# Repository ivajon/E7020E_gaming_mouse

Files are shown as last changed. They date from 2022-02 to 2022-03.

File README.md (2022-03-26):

# Awesome gaming mouse
The awesome gaming mouse project, the one mouse to rule them all. The schematics
are available [here](schematics_and_pcb). The firmware for the mouse is written in rust using [rtic](https://rtic.rs/) and is found [here](code/e7020e_rtic) the rtic app is in the example [rtic_simple_mouse](code/e7020e_rtic/examples/rtic_simple_mouse.rs). The program used to configure the mouse is found [here](code/hosted/rust_version).

## How to flash the mouse
To flash the mouse read [this](e7020e-project/code/e7020_rtic/README.md) to get the build dependecies. When the dependencis are in place it can be built, flashed and run with `cargo run --example rtic_simple_mouse --release`. Note! it can't be built in debug mode since this will create to big of a binary and will not fit on the flash of a stm32f401re.

## Members

- Erik Serrander
- eriser-8@student.ltu.se
  
- Ivar Jönsson
- ivajns-9@student.ltu.se

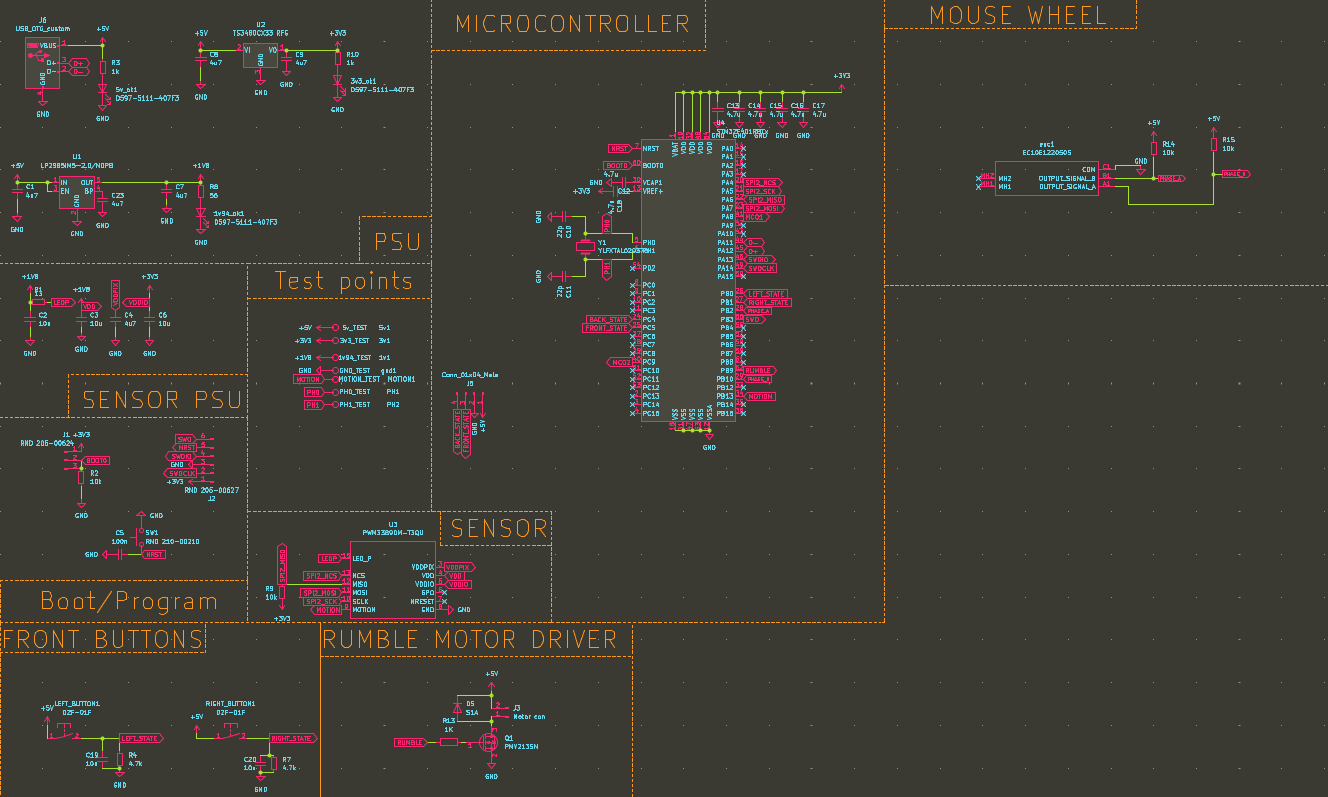
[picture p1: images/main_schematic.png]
main schematic


## High level specification

### Basic
- [x] Left and right click
- [x] relative position

### Higher
- [x] scroll wheel
- [x] macro system
- [x] Side buttons

### Stretch
- [x] Computer communication
- [ ] LEDs, i.e. debug/ui
- [ ] Rumble motor
- [ ] Perfect spray

### Implementation
- Unit testing
- Cuntinuous integration

# Specifications
## Mouse buttons
The buttons used are [D2F-01F](https://www.elfa.se/sv/mikrobrytare-d2f-100ma-1co-74n-kolv-omron-electronic-components-d2f-01f/p/11082662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) since these are well regarded by users.
We have decided to have 4 main buttons on the mouse, 2 on the front and 2 on the side.
## Side buttons 
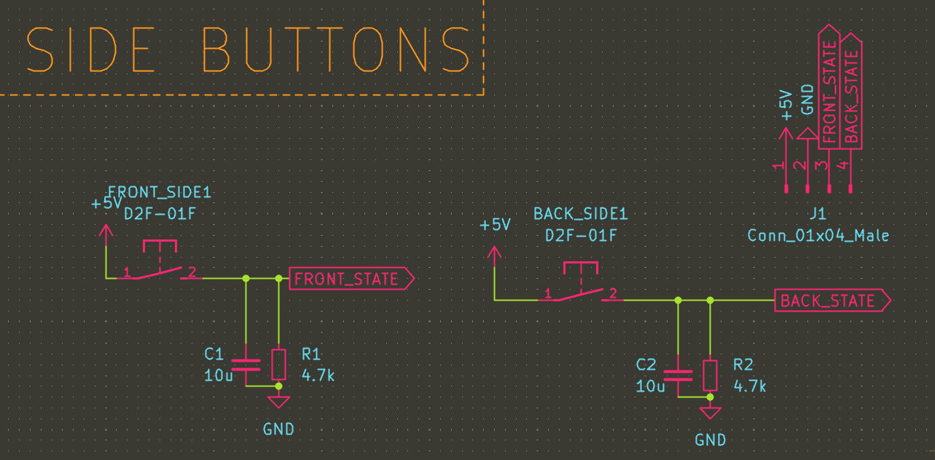
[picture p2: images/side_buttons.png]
side_buttons

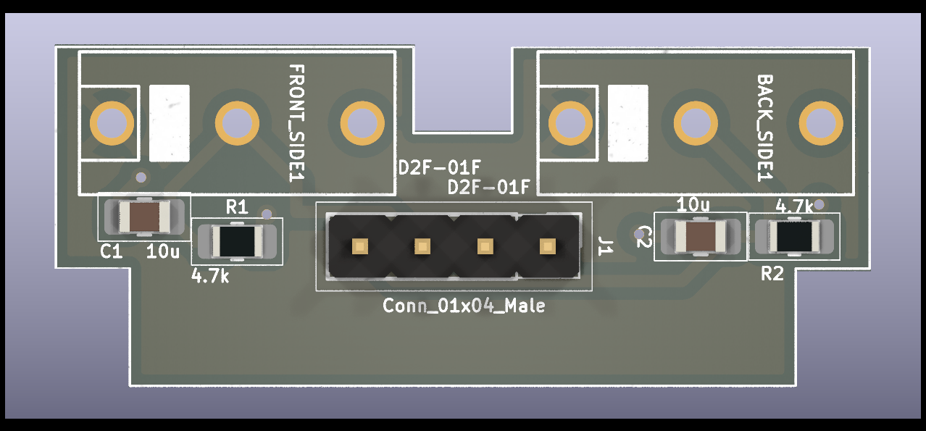
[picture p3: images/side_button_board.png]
side_pcb

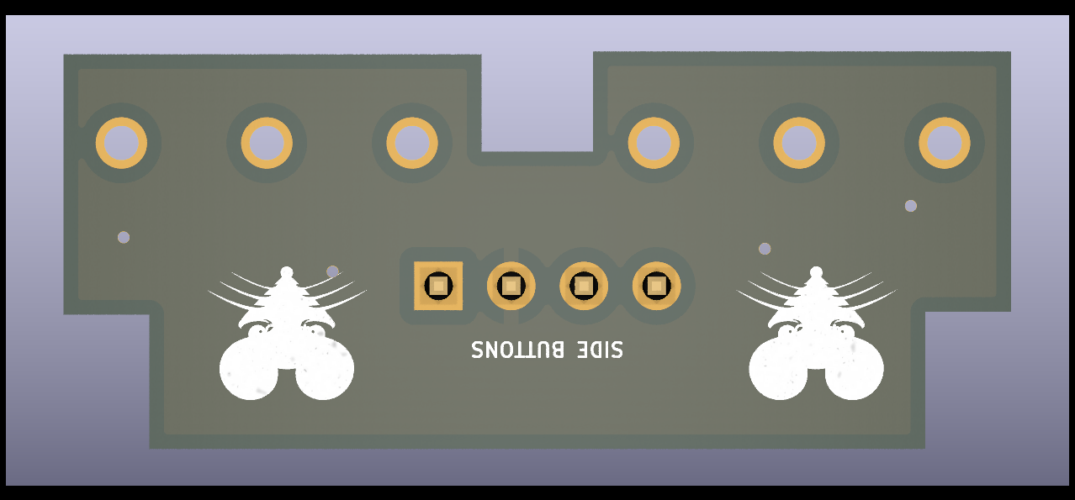
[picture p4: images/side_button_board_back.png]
side_pcb


To reduce the bouncing of the buttons a 10u capacitor is places to ground from the signal trace. This will allow the signal to be pulled low for high frequencies. 

To drive the buttons a 5v voltage is used with a series resistor of 4.7 k to limit the current to close to 1mA. The mosfet used to limit the output acts as a decoupler thus not draining anny current ( in theory ).

## Front buttons
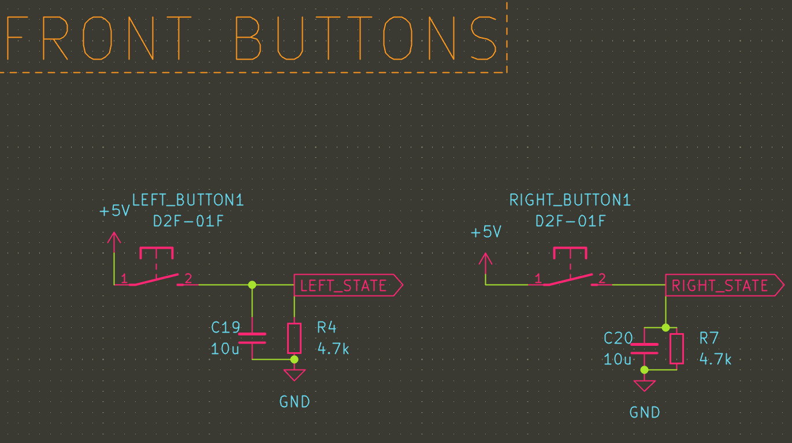
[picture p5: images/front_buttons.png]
front_buttons

## Mouse wheel

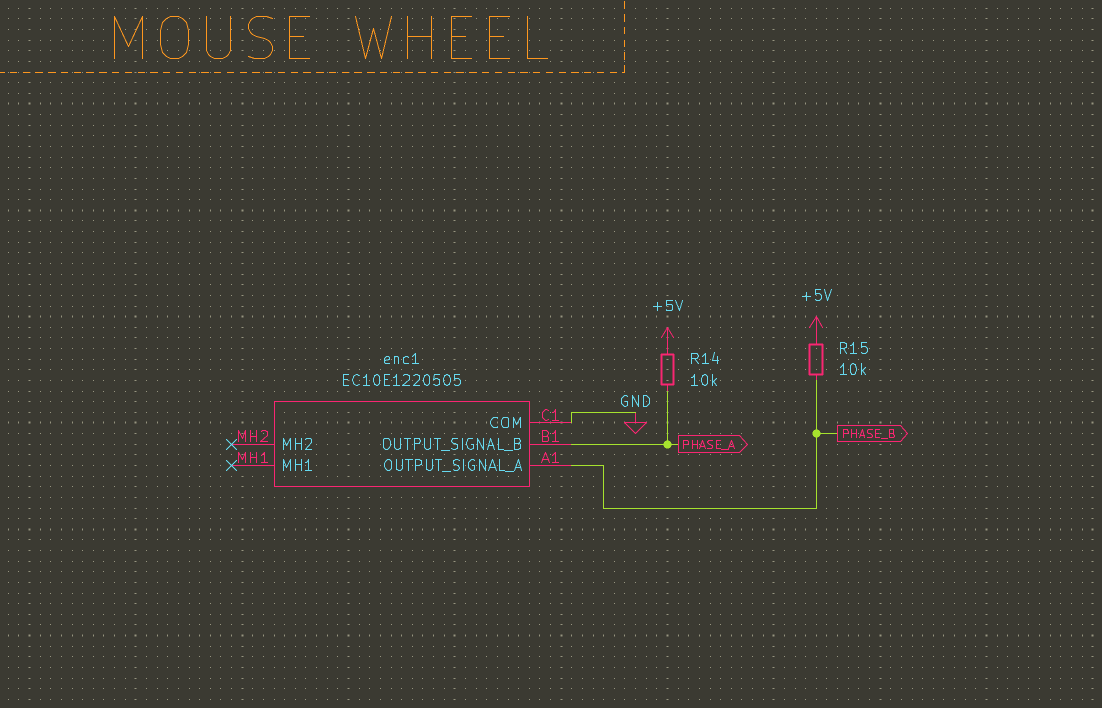
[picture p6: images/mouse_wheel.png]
mouse_wheel


The [mouse wheel](https://se.rs-online.com/web/p/mechanical-rotary-encoders/7295545) is also debounced using the same capacitor values as the mouse button. This should not be as needed but better safe than sorry.

The mouse wheel also uses the same nfet to step down the voltage.

## Rumble motor
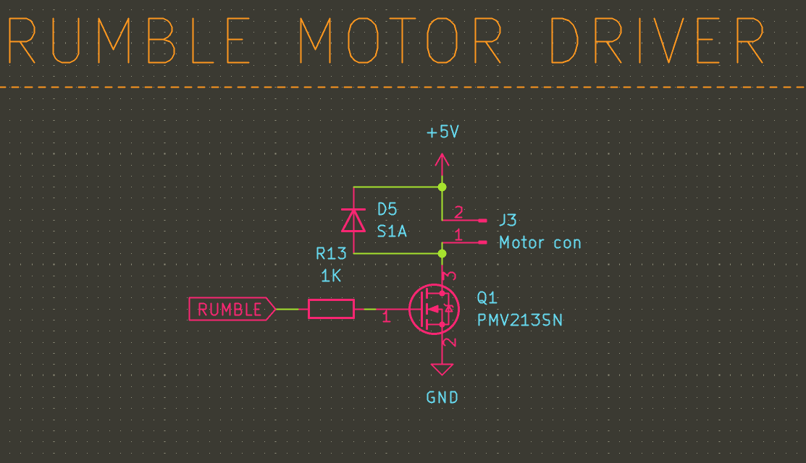
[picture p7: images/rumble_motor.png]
Rumble motor image


## Main board
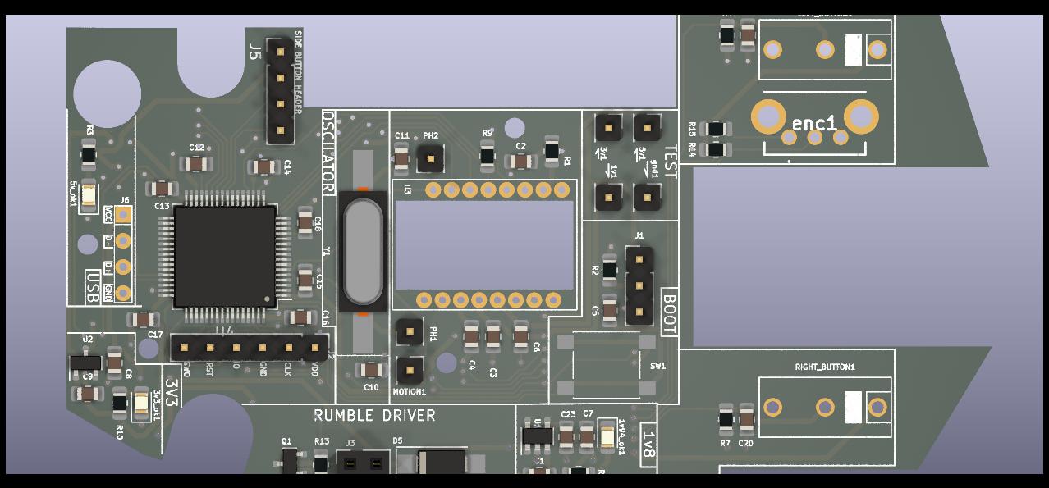
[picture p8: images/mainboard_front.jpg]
main board

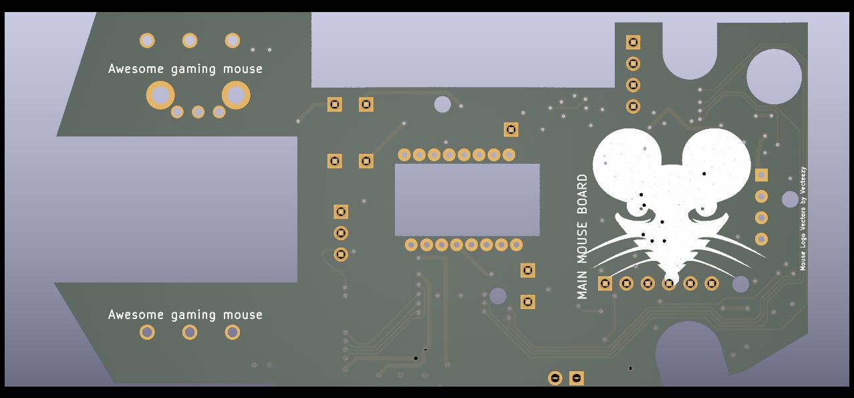
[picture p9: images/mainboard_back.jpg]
main board back


## Case 
We will base our case on this moddel of the [g305](https://www.thingiverse.com/thing:3969266)
with this [base](https://www.thingiverse.com/thing:3564894).

The stl files can be found in our [model folder](model/).

## Grading

- Erik Serrander
  - Expected contributions towards grade 4
    - side buttons
    - diodes
  - Expected contributions towards grade 5
    - Computer communication
    - Rumble motor
  
- Ivar Jönsson
  - Expected contributions towards grade 4
    - PCB layout
      - Itterative design using a 3d printer to validate pcb fitting and footprint layout
      - Ease of assembly
    - Case customization 
      - Mountingholes and posibility to use a usb cable
    - Mouse wheel
      - Selecting a rotary encoder
    - diodes
      - status LEDs to validate voltage sections
  - Expected contributions towards grade 5
    - Computer communication
    - DPI configuration
    - Perfect spray
      - This might not be applicable. 

## contributions

- Erik Serrander
  - Hardware design (werry minor)
  - Macro system
  - Macro system config mouse side
  - Mouse state software (major)

- Ivar Jönsson
  - Hardware design (allmost all)
  - Macro system config pc side
  - Mouse state software (minor)
  - Enclosure manufacturing

- Togheter / both
  - Init code
  - Interuppt handlers
  - Harware assembly

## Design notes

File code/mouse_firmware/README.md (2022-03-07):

# RTIC on the STM32F4xx Nucleo board

All tooling have been developed and tested under Linux. Any modern Linux distro should work, we usually recommend Arch linux as it provides a great package manager with rolling releases. If you want to run Arch, but don't want to install everything from scratch, you may opt for [Manjaro](https://manjaro.org/) or [Endeavour](https://endeavouros.com/). You will get the best user experience by a native install, but you may run Linux under a VM like virtualbox, or vmware (the player is free). You should install the guest extensions, to get better graphics performance (and perhaps better USB forwarding). Since you will connect your Nucleo using USB, you must make sure that USB port forwarding works (the Nucleo stlink programmer is a USB2 device running in full speed 12MBit).

This repo will be updated with more information throughout the course so please check the `CHANGELOG.md` and recent commits to see what has changed. (You should `pull` the upstream to keep your repository updated.) If you have suggestions to further improvements, please raise an issue and/or create a merge/pull request.

## Rust

We assume Rust to be installed using [rustup](https://www.rust-lang.org/tools/install).

Additionally you need to install the `thumbv7em-none-eabihf` target.

```shell
> rustup target add thumbv7em-none-eabihf 
```

You also need [cargo-binutils](https://github.com/rust-embedded/cargo-binutils), for inspecting the generated binaries. You install Rust applications through `cargo`

```shell
> cargo install cargo-binutils
```

There are a number of other useful [cargo subcommands](https://github.com/rust-lang/cargo/wiki/Third-party-cargo-subcommands).

- [cargo-bloat](https://crates.io/crates/cargo-bloat), for info on the size of different sections of the generated binary,
- [cargo-tree](https://crates.io/crates/cargo-tree) (that list your dependency tree), etc.

## For RTT tracing

Install the [probe-run](https://crates.io/crates/probe-run) tool.

```shell
> cargo install probe-run
```

Install the [cargo-embed](https://github.com/probe-rs/cargo-embed) tool.

```shell
> cargo install cargo-embed
```

Or for the latest git version, with improved support for blocking writes in case buffer space is depleted.

```shell
> cargo install --git https://github.com/probe-rs/cargo-embed.git
```

## For `itm` tracing in terminal

The SWO output pin of the MCU is used to transmit trace information over a single serial wire. The onboard Nucleo `stlink` programmer has an SWO input pin (by default connected to the target MCU). You can setup `openocd` to forward the serial communication to a file (or pipe). In order to view the trace as text, the serial stream needs to be decoded by some tool (e.g., the `itmdump` utility or the built in decoder in `Cortex Debug`). To install `itmdump`:

```shell
> cargo install itm
```

## For programming and low-level `gdb` based debugging

Use your Linux package manager to install the following tools:

- `stlink`, this package will install programming utilities like `st-flash` (useful if you need to recover a bricked target by erasing the flash), and setup `udev` rules, allowing you to access the USB device without `sudo`. Install may require you to login/logout to have new `udev` rules applied.

- `arm-none-eabi-gdb` (Arch), or `gdb-multiarch` (Ubuntu etc.). This tool allows you to program (flash) and debug your target.

- `openocd`, this tool allows the host to connect to the (stlink) programmer. The scripts used assume the latest `openocd-git` (0.11.0+dev).

  Under Arch: The official package (as of 2022-02-13) relates to a released 0.11.0 version of `openocd`, and will not likely work, you need a `dev` version. You can either install from source [openocd](https://github.com/openocd-org/openocd), or easier using a prepared package build:
  - Clone my repo [openocd-git](https://github.com/perlindgren/openocd-git/). (The official `aur` is outdated, so I made a fix.)

  - Install the package:

    ```shell
    > makepkg -si
    ```

  - Trouble shooting. If it fails to compile you might be missing some dependency provided by the `base-devel` package.
  
    ```shell
    > pacman -S base-devel
    ```

  Other Linux distributions: Either install from source or find a package relating to the git version of `openocd`.

- [stlink](https://www.st.com/en/development-tools/stsw-link007.html), firmware for the `st-link` programmer on your Nucleo board. You can obtain it free from ST web site, or under Arch use the `aur` package [stsw-link007](https://aur.archlinux.org/packages/stsw-link007). To run the firmware update in Arch:
  
  ```shell
  >STLinkUpgrade
  ```

  Once the Java application started you can flash a new firmware.
  Choose `Open in update mode`, leave `Change type` unchecked and click `Upgrade`.

## Editor

You may use any editor of choice. We recommend `vscode`, the `rust-analyzer` and `Cortex Debug` plugins. There are many other great plugins for improved git integration, `.md` linting and preview etc.

In the `.vscode` folder of this project, you find a number of configuration files (`launch.json` for target debugging, `tasks.json` for building, etc.), that facilitates embedded Rust development.

## Useful Resources

- Nucleo 64
  - [UM1724 - stm32 Nucleo-64](https://www.st.com/resource/en/user_manual/dm00105823-stm32-nucleo64-boards-mb1136-stmicroelectronics.pdf).
  - [Nucleo 64 Schematics](https://www.st.com/resource/en/schematic_pack/nucleo_64pins_sch.zip) (The file MB1136.pdf is the schematics in pdf.)
  - [stm32f4xx_hal](https://docs.rs/stm32f4xx-hal/0.8.3/stm32f4xx_hal/) documentation of the HAL API, and [git repository](https://github.com/stm32-rs/stm32f4xx-hal).

- STM32F01/FO11
  - [RM0383 - F411 Reference Manual](https://www.st.com/resource/zh/reference_manual/dm00119316-stm32f411xce-advanced-armbased-32bit-mcus-stmicroelectronics.pdf) 
  - [RM0368 - F401 Reference Manual](https://www.st.com/resource/en/reference_manual/dm00096844-stm32f401xbc-and-stm32f401xde-advanced-armbased-32bit-mcus-stmicroelectronics.pdf)
  - [PM0214 - M4 Programming manual](https://www.google.com/url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)

- PixArt PMW33xx Optical Navigation Chip
  - [PMW3389DM-T3QU](https://www.google.com/url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), optical navigation chip
  - [Jack Enterprise Breakout Board](https://www.tindie.com/products/jkicklighter/pmw3389-motion-sensor/), an example design with software linked.

- General Embedded
  - [Introduction to SPI](https://www.analog.com/en/analog-dialogue/articles/introduction-to-spi-interface.html#), a short introduction to the SPI interface.

---

## Examples

### Terminal trace using RTT

Select the runner in `.cargo/config.toml`:

```shell
runner = "probe-run --chip STM32F411RETx"
```

Run your application from terminal:

```shell
> cargo run --example rtt_rtic_hello
```

Tracing of panics is supported by the `panic_rtt` crate.

---

### VSCODE based debug and trace

Some simple bare metal examples for you to try out before starting to run your own code: (Here we assume the tools mentioned above have been successfully installed into their default locations. If you installed manually, you may need to tweak paths accordingly, ask in the `software` channel on Discord if you run into some trouble.)

Using `vscode` just press F5 to launch and debug the program in the currently active `vscode` window.

- `rtic_hello.rs`, this example uses semihosting to print the output terminal. In `vscode`:
  - `Terminal` pane `gdb-server` shows the `openocd` session (your semihosting trace will be displayed there).
  - `DEBUG CONSOLE` pane shows the `gdb` session. You can use this to interact directly with the target (over openocd).

- `itm_rtic_hello.rs`, this examples uses the ITM trace to print to trace channel 0. The `Terminal` pane `SWO:ITM[port:0] console]` will display the ITM trace.

- `rtic_panic.rs`, this example shows how to trace panic messages (in this case over semihosting).  Open the `Terminal` pane and select `gdb-server` (which is the `openocd` console).
  
---

### Terminal trace using semihosting

Select the runner in `.cargo/config.toml` according to your `gdb` install, e.g.:

```shell
runner = "arm-none-eabi-gdb -q -x openocd.gdb"
```

Start `openocd` in a separate terminal:

```shell
> openocd -f openocd.cfg
```

Run the application: e.g.

```shell
> cargo run rtic_hello
```

The `openocd.gdb` script is used to setup the behavior of the debug session, you may change it to your liking. (The default script puts breakpoints at `DefaultHandler`, `HardFault` and `main`, edit it for your needs.)

```shell
> cargo run rtic_hello
```

---

### Terminal trace using ITM

Setup the runner as for previous example.

To setup a fifo for the ITM stream and start sniffing:

```shell
> mkfifo /tmp/itm.fifo
> itmdump -F -f /tmp/itm.fifo
```

The `-F` instructs `itmdump` to follow the stream.

Start the `openocd` session in a separate terminal.

```shell
> openocd -f openocd.cfg
```

Start the `gdb` session in a separate terminal.

```shell
> cargo run ....
```

This, in this scenario you will have three terminals running:

- `itmdump`, to decoded and echo the ITM stream,
  
- `openocd`, to communicate to the programmer and provide a gdb-server,
  
- `arm-none-eabi-gdb`, to debug our application.

ITM traces should now appear in the `itmdump` terminal and semihosting traces in the `openocd` terminal.

---

### Gdb the GNU debugger

Gdb offers a lot of functionality, you may even write scripts in python to automate debugging. For a summary of commands see e.g., [gdb-refcard](http://fac-staff.seattleu.edu/elarson/web/Linux/gdb-refcard.pdf).

Many of the commands can be executed from the `DEBUG CONSOLE` in `vscode`.

---

### Concluding remarks on debug and trace

Chose the approach and tools dependent on your application needs. If plain tracing  is sufficient chose `probe run`. If you need to interactively debug your application, use `gdb` based trace and debug instead. ITM is preferred over semihosting for real-time applications.

You may also look at [defmt](https://crates.io/crates/defmt), it supports deferred formatting to reduce the run-time overhead (on the target).

---

### Exercises

Bare metal programming:

- `examples/rtic_bare1.rs`, in this exercise you learn about debugging, inspecting the generated assembly code, inline assembly, and about checked vs. unchecked (wrapping) arithmetics. Provides essential skills and understanding of low level (bare metal) programming.
- `examples/rtic_bare2.rs`, in this exercise you learn how to measure execution time using raw timer access.
- `examples/rtic_bare3.rs`, here you learn more about RTIC timing semantics and timing abstractions.
- `examples/rtic_bare4.rs`, in this exercise you will encounter a simple bare metal peripheral access API. The API is very unsafe and easy to misuse.
- `examples/rtic_bare5.rs`, here you will write your own C-like peripheral access API. This API is much safer as you get control over bit-fields in a well defined way, thus less error prone.

---

## Troubleshooting

---

### Fail to connect or program (flash) your target

- Make sure you have the latest version of the [stlink](https://www.st.com/en/development-tools/stsw-link007.html) firmware (V2J39M27 or later).

- Check that your stlink Nucleo programmer is found by the host.

  ```shell
  > lsusb
  ...
  Bus 003 Device 013: ID 0483:374b STMicroelectronics ST-LINK/V2.1
  ...
  ```

  If not check your USB cable. Notice, you need a USB data cable (not a USB charging cable).
  If the problem is still there, there might be a USB issue with the host (or VM if you run Linux under a VM that is).

- If you get a connection error similar to the below:

  ```shell
  > openocd -f openocd.cfg
  Open On-Chip Debugger 0.11.0+dev-00562-g5ab74bde0 (2022-02-09-11:34)
  Licensed under GNU GPL v2
  For bug reports, read
          http://openocd.org/doc/doxygen/bugs.html
  Info : auto-selecting first available session transport "hla_swd". To override use 'transport select <transport>'.
  Info : The selected transport took over low-level target control. The results might differ compared to plain JTAG/SWD
  Info : Listening on port 6666 for tcl connections
  Info : Listening on port 4444 for telnet connections
  Info : clock speed 2000 kHz
  Info : STLINK V2J39M27 (API v2) VID:PID 0483:374B
  Info : Target voltage: 3.234098
  Info : stm32f4x.cpu: Cortex-M4 r0p1 processor detected
  Info : stm32f4x.cpu: target has 6 breakpoints, 4 watchpoints
  Info : starting gdb server for stm32f4x.cpu on 3333
  Info : Listening on port 3333 for gdb connection
  Error: jtag status contains invalid mode value - communication failure
  Polling target stm32f4x.cpu failed, trying to reexamine
  Examination failed, GDB will be halted. Polling again in 100ms
  Info : Previous state query failed, trying to reconnect
  Error: jtag status contains invalid mode value - communication failure
  Polling target stm32f4x.cpu failed, trying to reexamine 
  ```

  - First thing to try is holding the reset button while connecting.

  - If this does not work you can try to erase the flash memory (the program running on the STM32F401/F11).

    ``` shell
    > st-flash erase
    st-flash 1.7.0
    2021-06-23T14:07:35 INFO common.c: F4xx (Dynamic Efficency): 96 KiB SRAM, 512 KiB flash in at least 16 KiB pages.
    Mass erasing.......
    ```

  - If this still does not work you can connect `Boot0` to `VDD` (found on CN7 pins 7, and 5 respectively). Unplug/replug the Nucleo and try to erase the flash as above.
  
  - If this still does not work, the Nucleo might actually been damaged, or that the problem is the usb-cable or host   machine related.

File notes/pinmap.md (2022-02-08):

|pin name | pin number | function | interrupt reg|
| --- | --- | --- | --- |
| PB0 | 26 |LEFT_STATE| EXTI line 0 |
| PB1 | 27 |RIGHT_STATE|EXTI line 1 |
| PB2 | 28 | PHASE A | EXT1 line 2 |
| PB3 | 55 |

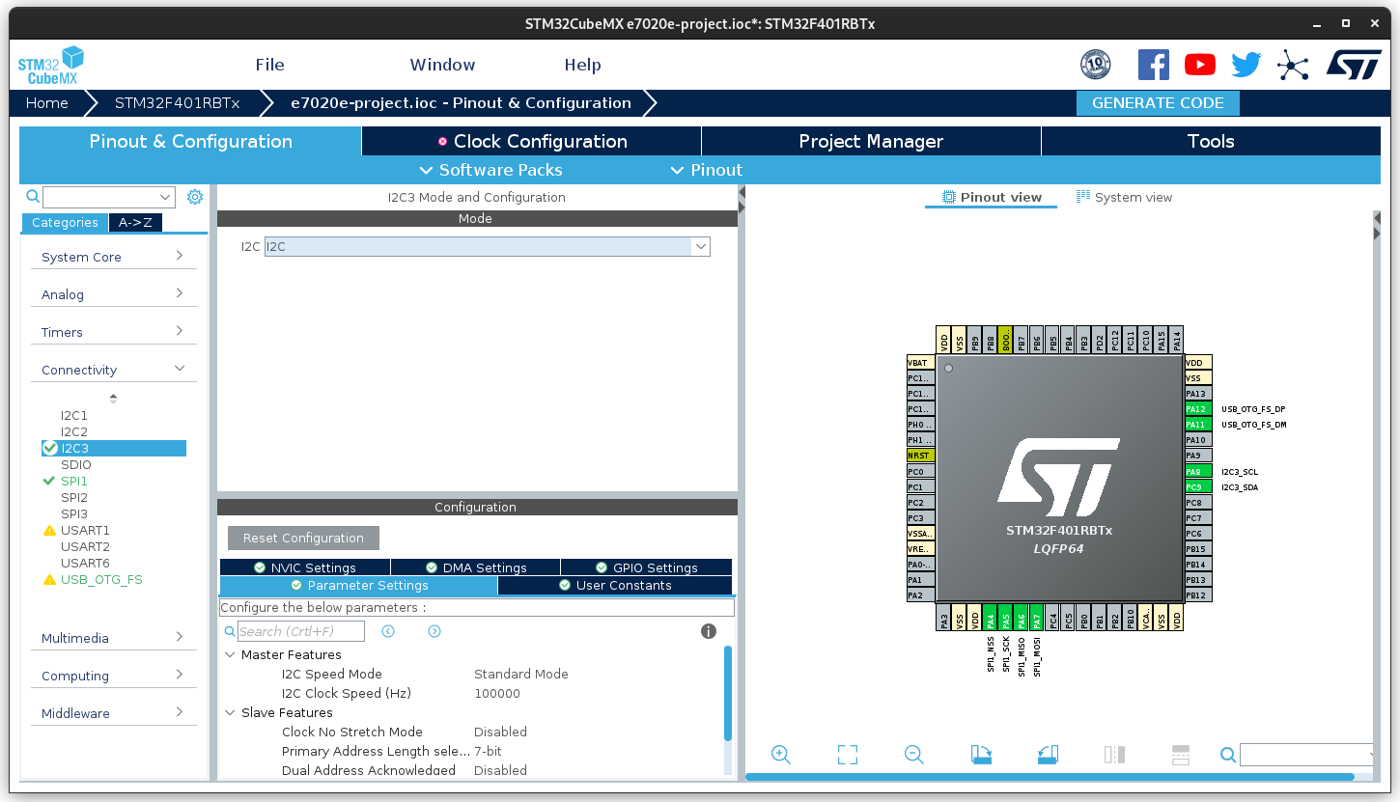
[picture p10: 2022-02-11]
images/Screenshot from 2022-02-11 10-17-43.png

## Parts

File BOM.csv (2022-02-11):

Source: | /home/ivarj/git/project/e7020e-project/schematics_and_pcb/schematics_and_pcb.kicad_sch
Date: | fre 11 feb 2022 14:17:39
Tool: | Eeschema (6.0.1)
Generator: | /usr/share/kicad/plugins/bom_csv_grouped_by_value.py
Component Count: | 82
Individual Components:
Item | Qty | Reference(s) | Value | LibPart | Footprint | Datasheet | Description | Height | Manufacturer_Name | Manufacturer_Part_Number | Mouser Part Number | Mouser Price/Stock | part #
 |  | 1v1 | 1v94_TEST | Connector:TestPoint | Connector_PinHeader_2.54mm:PinHeader_1x01_P2.54mm_Vertical | ~
 |  | 1v94_ok1 | D597-5111-407F3 | Device:LED | LED_SMD:LED_0805_2012Metric_Pad1.15x1.40mm_HandSolder | ~ |  |  |  |  |  |  | D597-5111-407F3
 |  | 3v1 | 3v3_TEST | Connector:TestPoint | Connector_PinHeader_2.54mm:PinHeader_1x01_P2.54mm_Vertical | ~
 |  | 3v3_ok1 | D597-5111-407F3 | Device:LED | LED_SMD:LED_0805_2012Metric_Pad1.15x1.40mm_HandSolder | ~ |  |  |  |  |  |  | D597-5111-407F3
 |  | 5v1 | 5v_TEST | Connector:TestPoint | Connector_PinHeader_2.54mm:PinHeader_1x01_P2.54mm_Vertical | ~
 |  | 5v_ok1 | D597-5111-407F3 | Device:LED | LED_SMD:LED_0805_2012Metric_Pad1.15x1.40mm_HandSolder | ~ |  |  |  |  |  |  | D597-5111-407F3
 |  | BACK_SIDE1 | D2F-01F | mouse:D2F-01F | mouse:D2F-01F
 |  | C1 | 4u7 | Device:C_Small | Capacitor_SMD:C_0805_2012Metric_Pad1.18x1.45mm_HandSolder | ~
 |  | C2 | 10u | Device:C_Small | Capacitor_SMD:C_0805_2012Metric_Pad1.18x1.45mm_HandSolder | ~
 |  | C3 | 10u | Device:C_Small | Capacitor_SMD:C_0805_2012Metric_Pad1.18x1.45mm_HandSolder | ~
 |  | C4 | 4u7 | Device:C_Small | Capacitor_SMD:C_0805_2012Metric_Pad1.18x1.45mm_HandSolder | ~
 |  | C5 | 100n | Device:C_Small | Capacitor_SMD:C_0805_2012Metric_Pad1.18x1.45mm_HandSolder | ~
 |  | C6 | 10u | Device:C_Small | Capacitor_SMD:C_0805_2012Metric_Pad1.18x1.45mm_HandSolder | ~
 |  | C7 | 4u7 | Device:C_Small | Capacitor_SMD:C_0805_2012Metric_Pad1.18x1.45mm_HandSolder | ~
 |  | C8 | 4u7 | Device:C_Small | Capacitor_SMD:C_0805_2012Metric_Pad1.18x1.45mm_HandSolder | ~
 |  | C9 | 4u7 | Device:C_Small | Capacitor_SMD:C_0805_2012Metric_Pad1.18x1.45mm_HandSolder | ~
 |  | C10 | 18p | Device:C_Small | Capacitor_SMD:C_0805_2012Metric_Pad1.18x1.45mm_HandSolder | ~
 |  | C11 | 18p | Device:C_Small | Capacitor_SMD:C_0805_2012Metric_Pad1.18x1.45mm_HandSolder | ~
 |  | C12 | 4.7u | Device:C_Small | Capacitor_SMD:C_0805_2012Metric_Pad1.18x1.45mm_HandSolder | ~
 |  | C13 | 4.7u | Device:C_Small | Capacitor_SMD:C_0805_2012Metric_Pad1.18x1.45mm_HandSolder | ~
 |  | C14 | 4.7u | Device:C_Small | Capacitor_SMD:C_0805_2012Metric_Pad1.18x1.45mm_HandSolder | ~
 |  | C15 | 4.7u | Device:C_Small | Capacitor_SMD:C_0805_2012Metric_Pad1.18x1.45mm_HandSolder | ~
 |  | C16 | 4.7u | Device:C_Small | Capacitor_SMD:C_0805_2012Metric_Pad1.18x1.45mm_HandSolder | ~
 |  | C17 | 4.7u | Device:C_Small | Capacitor_SMD:C_0805_2012Metric_Pad1.18x1.45mm_HandSolder | ~
 |  | C18 | 4.7u | Device:C_Small | Capacitor_SMD:C_0805_2012Metric_Pad1.18x1.45mm_HandSolder | ~
 |  | C19 | 10u | Device:C_Small | Capacitor_SMD:C_0805_2012Metric_Pad1.18x1.45mm_HandSolder | ~
 |  | C20 | 10u | Device:C_Small | Capacitor_SMD:C_0805_2012Metric_Pad1.18x1.45mm_HandSolder | ~
 |  | C21 | 10u | Device:C_Small | Capacitor_SMD:C_0805_2012Metric_Pad1.18x1.45mm_HandSolder | ~
 |  | C22 | 10u | Device:C_Small | Capacitor_SMD:C_0805_2012Metric_Pad1.18x1.45mm_HandSolder | ~
 |  | C23 | 4u7 | Device:C_Small | Capacitor_SMD:C_0805_2012Metric_Pad1.18x1.45mm_HandSolder | ~
 |  | C24 | 10u | Device:C_Small | Capacitor_SMD:C_0805_2012Metric_Pad1.18x1.45mm_HandSolder | ~
 |  | D5 | SS16HE | Diode:1N4001 | mouse:SOD-323HE | http://www.vishay.com/docs/88503/1n4001.pdf |  |  |  |  |  |  | SS16HE
 |  | enc1 | EC10E1220505 | mouse:EC10E1220505 | mouse:EC10E1220505 | https://tech.alpsalpine.com/prod/e/html/encoder/incremental/ec10e/ec10e1220505.html | 10mm Size Hollow Shaft Type EC10E Incremental Encoder | 10.6 | ALPS Electric | EC10E1220505 | 688-EC10E1220505 | https://www.mouser.co.uk/ProductDetail/Alps-Alpine/EC10E1220505?qs=seHrhfPpLDy2J0FZRG9wSg%3D%3D
 |  | FRONT_SIDE1 | D2F-01F | mouse:D2F-01F | mouse:D2F-01F
 |  | gnd1 | GND_TEST | Connector:TestPoint | Connector_PinHeader_2.54mm:PinHeader_1x01_P2.54mm_Vertical | ~
 |  | J1 | RND 205-00624 | Connector:Conn_01x03_Male | Connector_PinHeader_2.54mm:PinHeader_1x03_P2.54mm_Vertical | ~
 |  | J2 | RND 205-00627 | Connector:Conn_01x06_Male | Connector_PinHeader_2.54mm:PinHeader_1x06_P2.54mm_Vertical | ~
 |  | J3 | Motor con | Connector:Conn_01x02_Male | Connector_PinSocket_2.54mm:PinSocket_1x02_P2.54mm_Vertical | ~
 |  | J4 | Conn_01x04_Male | Connector:Conn_01x04_Male | Connector_PinHeader_2.54mm:PinHeader_1x04_P2.54mm_Vertical | ~
 |  | J5 | Conn_01x04_Male | Connector:Conn_01x04_Male | Connector_PinHeader_2.54mm:PinHeader_1x04_P2.54mm_Vertical | ~
 |  | J6 | USB_OTG_custom | mouse:USB_OTG_custom | mouse:USB_2.45 | ~
 |  | J7 | i2c header | Connector:Conn_01x04_Male | Connector_PinHeader_2.54mm:PinHeader_1x04_P2.54mm_Vertical | ~
 |  | J8 | i2c header | Connector:Conn_01x04_Male | Connector_PinHeader_2.54mm:PinHeader_1x04_P2.54mm_Vertical | ~
 |  | LEFT_BUTTON1 | D2F-01F | mouse:D2F-01F | mouse:D2F-01F |  |  |  |  |  |  |  | D2F-01F
 |  | MOTION1 | MOTION_TEST | Connector:TestPoint | Connector_PinHeader_2.54mm:PinHeader_1x01_P2.54mm_Vertical | ~
 |  | PH1 | PH0_TEST | Connector:TestPoint | Connector_PinHeader_2.54mm:PinHeader_1x01_P2.54mm_Vertical | ~
 |  | PH2 | PH1_TEST | Connector:TestPoint | Connector_PinHeader_2.54mm:PinHeader_1x01_P2.54mm_Vertical | ~
 |  | Q1 | TSM2308CX RFG | Device:Q_NMOS_GSD | Package_TO_SOT_SMD:SOT-23 | ~ |  |  |  |  |  |  | TSM2308CX RFG
 |  | R1 | 13 | Device:R_Small | Resistor_SMD:R_0805_2012Metric_Pad1.20x1.40mm_HandSolder | ~ |  |  |  |  |  |  | RND 155HP05W3F130JT5E
 |  | R2 | 10k | Device:R_Small | Resistor_SMD:R_0805_2012Metric_Pad1.20x1.40mm_HandSolder | ~ |  |  |  |  |  |  | RT0805FRE0710KL
 |  | R3 | 1k | Device:R_Small | Resistor_SMD:R_0805_2012Metric_Pad1.20x1.40mm_HandSolder | ~ |  |  |  |  |  |  | RC0805FR-071KL
 |  | R4 | 4.7k | Device:R_Small | Resistor_SMD:R_0805_2012Metric_Pad1.20x1.40mm_HandSolder | ~ |  |  |  |  |  |  | RC0805FR-074K7L
 |  | R5 | 10k | Device:R | Resistor_SMD:R_0805_2012Metric_Pad1.20x1.40mm_HandSolder | ~ |  |  |  |  |  |  | RC0805FR-071KL
 |  | R6 | 4.7k | Device:R_Small | Resistor_SMD:R_0805_2012Metric_Pad1.20x1.40mm_HandSolder | ~ |  |  |  |  |  |  | RC0805FR-074K7L
 |  | R7 | 4.7k | Device:R_Small | Resistor_SMD:R_0805_2012Metric_Pad1.20x1.40mm_HandSolder | ~ |  |  |  |  |  |  | RC0805FR-074K7L
 |  | R8 | 56 | Device:R_Small | Resistor_SMD:R_0805_2012Metric_Pad1.20x1.40mm_HandSolder | ~ |  |  |  |  |  |  | RND 155HP05W3F560JT5E
 |  | R9 | 10k | Device:R_Small | Resistor_SMD:R_0805_2012Metric_Pad1.20x1.40mm_HandSolder | ~ |  |  |  |  |  |  | RT0805FRE0710KL
 |  | R10 | 1k | Device:R_Small | Resistor_SMD:R_0805_2012Metric_Pad1.20x1.40mm_HandSolder | ~ |  |  |  |  |  |  | RC0805FR-071KL
 |  | R11 | 4.7k | Device:R_Small | Resistor_SMD:R_0805_2012Metric_Pad1.20x1.40mm_HandSolder | ~ |  |  |  |  |  |  | RC0805FR-074K7L
 |  | R12 | 4.7k | Device:R_Small | Resistor_SMD:R_0805_2012Metric_Pad1.20x1.40mm_HandSolder | ~ |  |  |  |  |  |  | RC0805FR-074K7L
 |  | R13 | 680m | Device:R_Small | Resistor_SMD:R_0805_2012Metric_Pad1.20x1.40mm_HandSolder | ~
 |  | R14 | 10k | Device:R_Small | Resistor_SMD:R_0805_2012Metric_Pad1.20x1.40mm_HandSolder | ~ |  |  |  |  |  |  | RT0805FRE0710KL
 |  | R15 | 10k | Device:R_Small | Resistor_SMD:R_0805_2012Metric_Pad1.20x1.40mm_HandSolder | ~ |  |  |  |  |  |  | RT0805FRE0710KL
 |  | R16 | 680m | Device:R_Small | Resistor_SMD:R_0805_2012Metric_Pad1.20x1.40mm_HandSolder | ~
 |  | R17 | 8.1999999999999993 | Device:R_Small | Resistor_SMD:R_0805_2012Metric_Pad1.20x1.40mm_HandSolder | ~
 |  | R18 | 10k | Device:R_Small | Resistor_SMD:R_0805_2012Metric_Pad1.20x1.40mm_HandSolder | ~
 |  | R19 | 10k | Device:R_Small | Resistor_SMD:R_0805_2012Metric_Pad1.20x1.40mm_HandSolder | ~ |  |  |  |  |  |  | RT0805FRE0710KL
 |  | RIGHT_BUTTON1 | D2F-01F | mouse:D2F-01F | mouse:D2F-01F |  |  |  |  |  |  |  | D2F-01F
 |  | SW1 | RND 210-00210 | Switch:SW_Push | Button_Switch_SMD:SW_Push_1P1T_NO_6x6mm_H9.5mm | ~
 |  | SW2 | SW_Push | Switch:SW_Push | mouse:evqP0E07 | ~ |  |  |  |  |  |  | evqP0E07
 |  | U1 | LP2985IM5-2.0/NOPB | Regulator_Linear:MIC5205-2.5YM5 | Package_TO_SOT_SMD:SOT-23-5 | https://www.ti.com/lit/ds/symlink/lp2985lv-n.pdf?HQS=dis-mous-null-mousermode-dsf-pf-null-wwe&ts=1644322369088 |  |  |  |  |  |  | LP2985IM5-2.0/NOPB
 |  | U2 | TS3480CX33 RFG | Regulator_Linear:AP2127N-3.3 | Package_TO_SOT_SMD:SOT-23 | https://www.diodes.com/assets/Datasheets/AP2127.pdf |  |  |  |  |  |  | TS3480CX33 RFG
 |  | U3 | PWM3389DM-T3QU | mouse:PWM3389DM-T3QU | mouse:PMW3389DM-T3QU |  |  |  |  |  |  |  | PWM3389DM-T3QU
 |  | U4 | STM32F401RBTx | MCU_ST_STM32F4:STM32F401RBTx | Package_QFP:LQFP-64_10x10mm_P0.5mm | http://www.st.com/st-web-ui/static/active/en/resource/technical/document/datasheet/DM00086815.pdf
 |  | U5 | LFXTAL055951 | mouse:LFXTAL055951 | mouse:LFXTAL055951
 |  | U6 | 9DB403DGLFT | mouse:TSSOP28 | mouse:TSSOP-24
 |  | U7 | RND 135-00249 | mouse:RND 135-00249 | mouse:RND_135-00249
 |  | U8 | RND 135-00249 | mouse:RND 135-00249 | mouse:RND_135-00249
 |  | U9 | RND 135-00249 | mouse:RND 135-00249 | mouse:RND_135-00249
 |  | U10 | RND 135-00249 | mouse:RND 135-00249 | mouse:RND_135-00249
 |  | U11 | RND 135-00249 | mouse:RND 135-00249 | mouse:RND_135-00249
 |  | U12 | RND 135-00249 | mouse:RND 135-00249 | mouse:RND_135-00249
Replacing all the pinheaders with one of these
https://www.elfa.se/en/ss-straight-male-pcb-header-through-hole-rows-36-contacts-54mm-pitch-prostar-ss-1x36-t1-3mm/p/14370219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
Collated Components:
Item | Qty | Reference(s) | Value | LibPart | Footprint | Datasheet | Description | Height | Manufacturer_Name | Manufacturer_Part_Number | extended price | price | part # | in stock | min order | diff to max order | price at max | link
1 | 1 | 1v1 | 1v94_TEST | Connector:TestPoint | Connector_PinHeader_2.54mm:PinHeader_1x01_P2.54mm_Vertical | ~ |  |  |  |  | 0 | 0 | n/a | /home/ivarj/git/project/e7020e-project/schematics_and_pcb/schematics_and_pcb.kicad_sch | 0 | 0 | 0
2 | 3 | 1v94_ok1, 3v3_ok1, 5v_ok1 | D597-5111-407F3 | Device:LED | LED_SMD:LED_0805_2012Metric_Pad1.15x1.40mm_HandSolder | ~ |  |  |  |  | 34.859999999999999 | 5.8099999999999996 | D597-5111-407F3 | /home/ivarj/git/project/e7020e-project/schematics_and_pcb/schematics_and_pcb.kicad_sch | 3 | 0 | 0 | https://www.elfa.se/sv/lysdiod-smd-roed-647nm-25ma-7v-150-dialight-597-5111-407f/p/30133721
3 | 1 | 3v1 | 3v3_TEST | Connector:TestPoint | Connector_PinHeader_2.54mm:PinHeader_1x01_P2.54mm_Vertical | ~ |  |  |  |  | 0 | 0 | n/a | /home/ivarj/git/project/e7020e-project/schematics_and_pcb/schematics_and_pcb.kicad_sch | 0 | 0 | 0
4 | 1 | 5v1 | 5v_TEST | Connector:TestPoint | Connector_PinHeader_2.54mm:PinHeader_1x01_P2.54mm_Vertical | ~ |  |  |  |  | 0 | 0 | n/a | /home/ivarj/git/project/e7020e-project/schematics_and_pcb/schematics_and_pcb.kicad_sch | 0 | 0 | 0
5 | 4 | BACK_SIDE1, FRONT_SIDE1, LEFT_BUTTON1, RIGHT_BUTTON1 | D2F-01F | mouse:D2F-01F | mouse:D2F-01F |  |  |  |  |  | 82.400000000000006 | 10.300000000000001 | D2F-01F | /home/ivarj/git/project/e7020e-project/schematics_and_pcb/schematics_and_pcb.kicad_sch | 3 | 0 | 0 | https://www.elfa.se/en/micro-switch-d2f-100ma-1co-74n-plunger-omron-electronic-components-d2f-01f/p/11082662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
6 | 13 | C1, C4, C7, C8, C9, C23, C12, C13, C14, C15, C16, C17, C18 | 4u7 | Device:C_Small | Capacitor_SMD:C_0805_2012Metric_Pad1.18x1.45mm_HandSolder | ~ |  |  |  |  | 24.310000000000002 | 0.93500000000000005 | CL21A475KAQNNNE | /home/ivarj/git/project/e7020e-project/schematics_and_pcb/schematics_and_pcb.kicad_sch | 5 | 0 | 0 | https://se.farnell.com/samsung-electro-mechanics/cl21a475kaqnnne/cap-4-7uf-25v-mlcc-0805/dp/3013462
7 | 8 | C2, C3, C6, C19, C20, C21, C22, C24 | 10u | Device:C_Small | Capacitor_SMD:C_0805_2012Metric_Pad1.18x1.45mm_HandSolder | ~ |  |  |  |  | 29.120000000000001 | 1.8200000000000001 | CC0805KKX5R6BB106 | /home/ivarj/git/project/e7020e-project/schematics_and_pcb/schematics_and_pcb.kicad_sch | 50 | 34 | 61.880000000000003
8 | 1 | C5 | 100n | Device:C_Small | Capacitor_SMD:C_0805_2012Metric_Pad1.18x1.45mm_HandSolder | ~ |  |  |  |  | 0 | 0 | n/a | /home/ivarj/git/project/e7020e-project/schematics_and_pcb/schematics_and_pcb.kicad_sch | 0 | 0 | 0
9 | 2 | C10, C11 | 18p | Device:C_Small | Capacitor_SMD:C_0805_2012Metric_Pad1.18x1.45mm_HandSolder | ~ |  |  |  |  | 1.8200000000000001 | 0.45500000000000002 | C0805C180J5GACTU | /home/ivarj/git/project/e7020e-project/schematics_and_pcb/schematics_and_pcb.kicad_sch | 10 | 6 | 2.73 | https://se.rs-online.com/web/p/mlccs-multilayer-ceramic-capacitors/6480935
11 | 1 | D5 | SS16HE | Diode:1N4001 | mouse:SOD-323HE | http://www.vishay.com/docs/88503/1n4001.pdf |  |  |  |  | 8.7799999999999994 | 4.3899999999999997 | SS16HE | /home/ivarj/git/project/e7020e-project/schematics_and_pcb/schematics_and_pcb.kicad_sch |  | 0 | 0 | https://www.elfa.se/en/schottky-diode-1a-60v-sod-323he-onsemi-ss16he/p/30230979?queryFromSuggest=true
12 | 1 | enc1 | EC10E1220505 | mouse:EC10E1220505 | mouse:EC10E1220505 | https://tech.alpsalpine.com/prod/e/html/encoder/incremental/ec10e/ec10e1220505.html | 10mm Size Hollow Shaft Type EC10E Incremental Encoder | 10.6 | ALPS Electric | EC10E1220505 | 16.420000000000002 | 8.2100000000000009 | EC10E1220505 | /home/ivarj/git/project/e7020e-project/schematics_and_pcb/schematics_and_pcb.kicad_sch | 10 | 8 | 65.680000000000007 | https://se.farnell.com/alps/ec10e1220505/encoder-horiz-10mm-24det-12ppr/dp/2064974
13 | 1 | gnd1 | GND_TEST | Connector:TestPoint | Connector_PinHeader_2.54mm:PinHeader_1x01_P2.54mm_Vertical | ~ |  |  |  |  | 0 | 0 | n/a | /home/ivarj/git/project/e7020e-project/schematics_and_pcb/schematics_and_pcb.kicad_sch | 0 | 0 | 0
14 | 1 | J1 | RND 205-00624 | Connector:Conn_01x03_Male | Connector_PinHeader_2.54mm:PinHeader_1x03_P2.54mm_Vertical | ~ |  |  |  |  | 0 | 0 | RND 205-00624 | /home/ivarj/git/project/e7020e-project/schematics_and_pcb/schematics_and_pcb.kicad_sch | 50 | 48 | 0 | https://www.elfa.se/en/straight-male-pcb-header-through-hole-rows-contacts-54mm-pitch-rnd-connect-rnd-205-00624/p/30093644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
15 | 1 | J2 | RND 205-00627 | Connector:Conn_01x06_Male | Connector_PinHeader_2.54mm:PinHeader_1x06_P2.54mm_Vertical | ~ |  |  |  |  | 0 | 0 | RND 205-00627 | /home/ivarj/git/project/e7020e-project/schematics_and_pcb/schematics_and_pcb.kicad_sch | 25 | 23 | 0
16 | 1 | J3 | Motor con | Connector:Conn_01x02_Male | Connector_PinSocket_2.54mm:PinSocket_1x02_P2.54mm_Vertical | ~ |  |  |  |  | 0 | 0 | n/a | /home/ivarj/git/project/e7020e-project/schematics_and_pcb/schematics_and_pcb.kicad_sch | 0 | 0 | 0
17 | 2 | J4, J5 | Conn_01x04_Male | Connector:Conn_01x04_Male | Connector_PinHeader_2.54mm:PinHeader_1x04_P2.54mm_Vertical | ~ |  |  |  |  | 0 | 0 | n/a | /home/ivarj/git/project/e7020e-project/schematics_and_pcb/schematics_and_pcb.kicad_sch | 0 | 0 | 0
18 | 1 | J6 | USB_OTG_custom | mouse:USB_OTG_custom | mouse:USB_2.45 | ~ |  |  |  |  | 0 | 0 | n/a | /home/ivarj/git/project/e7020e-project/schematics_and_pcb/schematics_and_pcb.kicad_sch | 0 | 0 | 0
19 | 2 | J7, J8 | i2c header | Connector:Conn_01x04_Male | Connector_PinHeader_2.54mm:PinHeader_1x04_P2.54mm_Vertical | ~ |  |  |  |  | 0 | 0 | n/a | /home/ivarj/git/project/e7020e-project/schematics_and_pcb/schematics_and_pcb.kicad_sch | 0 | 0 | 0
20 | 1 | MOTION1 | MOTION_TEST | Connector:TestPoint | Connector_PinHeader_2.54mm:PinHeader_1x01_P2.54mm_Vertical | ~ |  |  |  |  | 0 | 0 | n/a | /home/ivarj/git/project/e7020e-project/schematics_and_pcb/schematics_and_pcb.kicad_sch | 0 | 0 | 0
21 | 1 | PH1 | PH0_TEST | Connector:TestPoint | Connector_PinHeader_2.54mm:PinHeader_1x01_P2.54mm_Vertical | ~ |  |  |  |  | 0 | 0 | n/a | /home/ivarj/git/project/e7020e-project/schematics_and_pcb/schematics_and_pcb.kicad_sch | 0 | 0 | 0
22 | 1 | PH2 | PH1_TEST | Connector:TestPoint | Connector_PinHeader_2.54mm:PinHeader_1x01_P2.54mm_Vertical | ~ |  |  |  |  | 0 | 0 | n/a | /home/ivarj/git/project/e7020e-project/schematics_and_pcb/schematics_and_pcb.kicad_sch | 0 | 0 | 0
23 | 1 | Q1 | TSM2308CX RFG | Device:Q_NMOS_GSD | Package_TO_SOT_SMD:SOT-23 | ~ |  |  |  |  | 10.42 | 5.21 | TSM2308CX RFG | /home/ivarj/git/project/e7020e-project/schematics_and_pcb/schematics_and_pcb.kicad_sch | 3 | 1 | 5.21 | https://www.elfa.se/en/mosfet-single-channel-60v-3a-25w-sot-23-taiwan-semiconductor-tsm2308cx-rfg/p/30139432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
24 | 1 | R1 | 15 | Device:R_Small | Resistor_SMD:R_0805_2012Metric_Pad1.20x1.40mm_HandSolder | ~ |  |  |  |  | 0 | 0 | n/a | /home/ivarj/git/project/e7020e-project/schematics_and_pcb/schematics_and_pcb.kicad_sch | 0 | 0 | 0 | https://www.elfa.se/en/high-power-thick-film-smd-resistor-0805-13ohm-330mw-rnd-components-rnd-155hp05w3f130jt5e/p/30111773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
25 | 7 | R2, R9, R14, R15, R18, R19, R5 | 10k | Device:R_Small | Resistor_SMD:R_0805_2012Metric_Pad1.20x1.40mm_HandSolder | ~ |  |  |  |  | 19.739999999999998 | 1.4099999999999999 | KTR10EZPF1002 | /home/ivarj/git/project/e7020e-project/schematics_and_pcb/schematics_and_pcb.kicad_sch | 10 | 0 | 0 | https://se.farnell.com/rohm/ktr10ezpf1002/res-10k-1-0-125w-0805-thick-film/dp/2919056
26 | 2 | R3, R10 | 1k | Device:R_Small | Resistor_SMD:R_0805_2012Metric_Pad1.20x1.40mm_HandSolder | ~ |  |  |  |  | 0 | 0 | n/a | /home/ivarj/git/project/e7020e-project/schematics_and_pcb/schematics_and_pcb.kicad_sch | 0 | 0 | 0
27 | 5 | R4, R6, R7, R11, R12 | 4.7k | Device:R_Small | Resistor_SMD:R_0805_2012Metric_Pad1.20x1.40mm_HandSolder | ~ |  |  |  |  | 0 | 0 | n/a | /home/ivarj/git/project/e7020e-project/schematics_and_pcb/schematics_and_pcb.kicad_sch | 0 | 0 | 0
29 | 1 | R8 | 56 | Device:R_Small | Resistor_SMD:R_0805_2012Metric_Pad1.20x1.40mm_HandSolder | ~ |  |  |  |  | 0 | 0 | n/a | /home/ivarj/git/project/e7020e-project/schematics_and_pcb/schematics_and_pcb.kicad_sch | 0 | 0 | 0
30 | 2 | R13, R16 | 1 | Device:R_Small | Resistor_SMD:R_0805_2012Metric_Pad1.20x1.40mm_HandSolder | ~ |  |  |  |  | 5.3200000000000003 | 1.3300000000000001 | CRCW08051R00JNEAHP | /home/ivarj/git/project/e7020e-project/schematics_and_pcb/schematics_and_pcb.kicad_sch | 0 | 0 | 0
31 | 1 | R17 | 10 | Device:R_Small | Resistor_SMD:R_0805_2012Metric_Pad1.20x1.40mm_HandSolder | ~ |  |  |  |  | 0 | 0 | n/a | /home/ivarj/git/project/e7020e-project/schematics_and_pcb/schematics_and_pcb.kicad_sch | 0 | 0 | 0
32 | 1 | SW1 | RND 210-00210 | Switch:SW_Push | Button_Switch_SMD:SW_Push_1P1T_NO_6x6mm_H9.5mm | ~ |  |  |  |  | 6.3399999999999999 | 3.1699999999999999 | RND 210-00210 | /home/ivarj/git/project/e7020e-project/schematics_and_pcb/schematics_and_pcb.kicad_sch | 10 | 8 | 25.359999999999999 | https://www.elfa.se/en/pcb-tactile-switch-1no-45n-6mm-rnd-components-rnd-210-00210/p/30090666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
33 | 1 | SW2 | SW_Push | Switch:SW_Push | mouse:evqP0E07 | ~ |  |  |  |  | 7.5199999999999996 | 3.7599999999999998 | evqP0E07 | /home/ivarj/git/project/e7020e-project/schematics_and_pcb/schematics_and_pcb.kicad_sch | 10 | 8 | 30.079999999999998 | https://se.farnell.com/en-SE/panasonic/evqp0e07k/switch-6-2x6-2mm-0-74n/dp/2079570?st=evqp0e07
34 | 1 | U1 | LP2985IM5-2.0/NOPB | Regulator_Linear:MIC5205-2.5YM5 | Package_TO_SOT_SMD:SOT-23-5 | https://www.ti.com/lit/ds/symlink/lp2985lv-n.pdf?HQS=dis-mous-null-mousermode-dsf-pf-null-wwe&ts=1644322369088 |  |  |  |  | 5.2679999999999998 | 2.6339999999999999 | LP2985IM5-2.0/NOPB | /home/ivarj/git/project/e7020e-project/schematics_and_pcb/schematics_and_pcb.kicad_sch | 10 | 8 | 21.071999999999999 | https://se.rs-online.com/web/p/voltage-regulators/8258257
35 | 1 | U2 | TS3480CX33 RFG | Regulator_Linear:AP2127N-3.3 | Package_TO_SOT_SMD:SOT-23 | https://www.diodes.com/assets/Datasheets/AP2127.pdf |  |  |  |  | 16.16 | 8.0800000000000001 | TS3480CX33 RFG | /home/ivarj/git/project/e7020e-project/schematics_and_pcb/schematics_and_pcb.kicad_sch | 3 | 1 | 8.0800000000000001 | https://www.elfa.se/en/ldo-voltage-regulator-3v-100ma-sot-23-taiwan-semiconductor-ts3480cx33-rfg/p/30139386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
36 | 1 | U3 | PWM3389DM-T3QU | mouse:PWM3389DM-T3QU | mouse:PMW3389DM-T3QU |  |  |  |  |  | 0 | 0 | PWM3389DM-T3QU | /home/ivarj/git/project/e7020e-project/schematics_and_pcb/schematics_and_pcb.kicad_sch | 0 | 0 | 0
37 | 1 | U4 | STM32F401RBTx | MCU_ST_STM32F4:STM32F401RBTx | Package_QFP:LQFP-64_10x10mm_P0.5mm | http://www.st.com/st-web-ui/static/active/en/resource/technical/document/datasheet/DM00086815.pdf |  |  |  |  | 0 | 0 | n/a | /home/ivarj/git/project/e7020e-project/schematics_and_pcb/schematics_and_pcb.kicad_sch | 0 | 0 | 0
38 | 1 | U5 | LFXTAL055951 | mouse:LFXTAL055951 | mouse:LFXTAL055951 |  |  |  |  |  | 13.699999999999999 | 6.8499999999999996 | LFXTAL055951 | /home/ivarj/git/project/e7020e-project/schematics_and_pcb/schematics_and_pcb.kicad_sch | 3 | 1 | 6.8499999999999996 | https://www.elfa.se/en/quartz-surface-mount-16mhz-iqd-lfxtal055951/p/30131299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
39 | 1 | U6 | 9DB403DGLFT | mouse:TSSOP28 | mouse:TSSOP-24 |  |  |  |  |  | 0 |  |  | /home/ivarj/git/project/e7020e-project/schematics_and_pcb/schematics_and_pcb.kicad_sch |  | 0 | 0
40 | 6 | U7, U8, U9, U10, U11, U12 | RND 135-00249 | mouse:RND 135-00249 | mouse:RND_135-00249 |  |  |  |  |  | 15.720000000000001 | 1.3100000000000001 | RND 135-00249 | /home/ivarj/git/project/e7020e-project/schematics_and_pcb/schematics_and_pcb.kicad_sch | 50 | 38 | 49.780000000000001 | https://www.elfa.se/en/rgb-smd-led-0606-468nm-520nm-632nm-rnd-components-rnd-135-00249/p/30158844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
price per mouse if comon order | 297.89800000000002
Price per mouse if not | 574.62
price pcb | 160
Total price if comon order | Total price if not
457.89800000000002 | 860.56500000000005

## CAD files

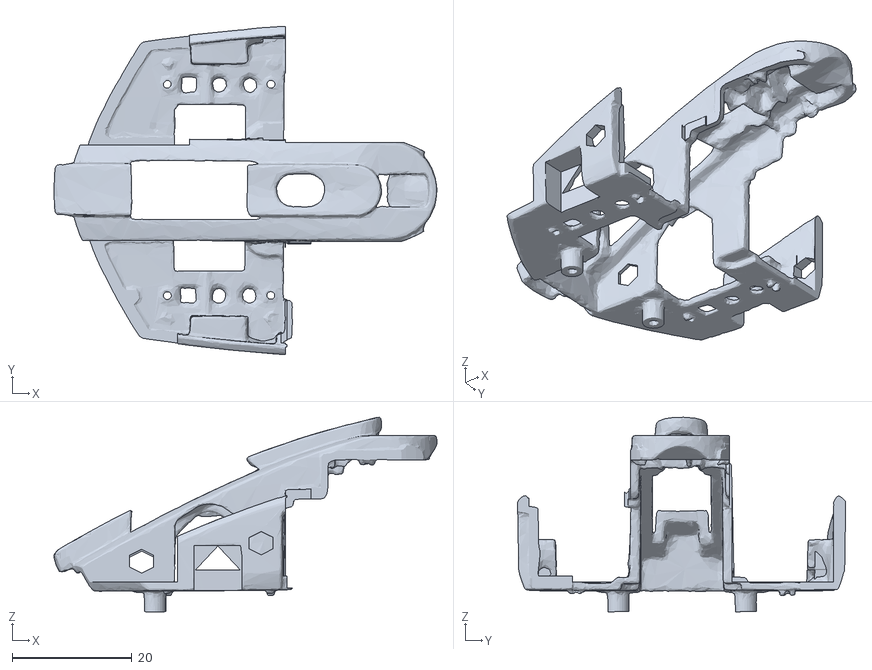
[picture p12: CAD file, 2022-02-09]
model/g305_subframe.stl
64.1 x 54.9 x 32.6

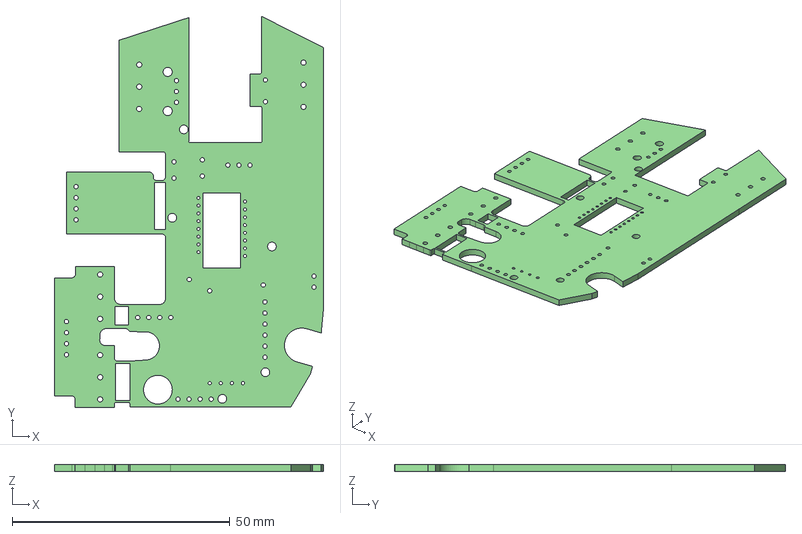
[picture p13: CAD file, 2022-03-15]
schematics_and_pcb/Ivar_Erik_rev1.step
61.8 x 89.9 x 1.60 mm

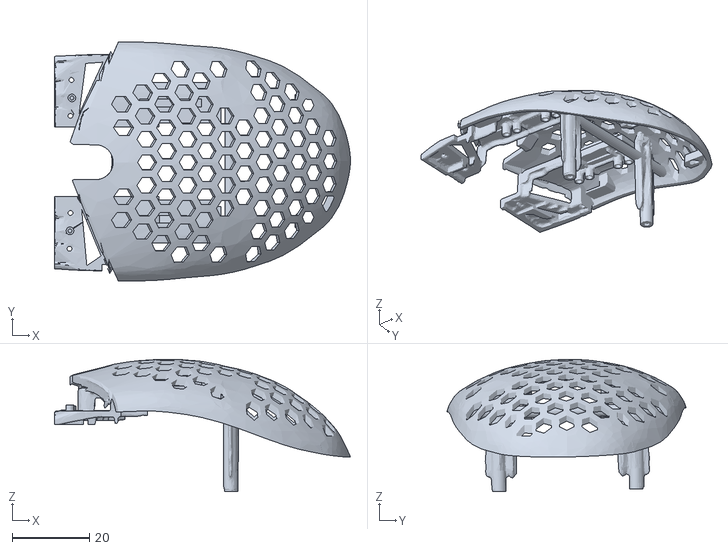
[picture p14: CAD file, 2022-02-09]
model/g305_top_ultra_light.stl
76.5 x 61.8 x 34.2

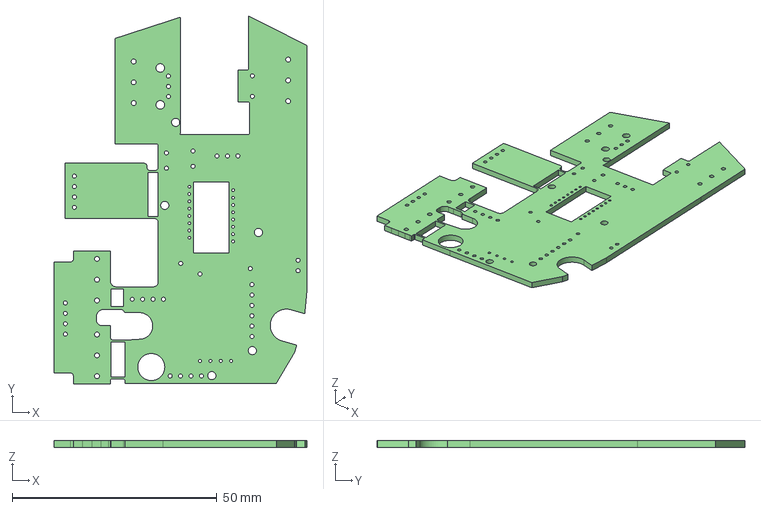
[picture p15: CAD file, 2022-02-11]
schematics_and_pcb/schematics_and_pcb.step
61.8 x 89.9 x 1.60 mm

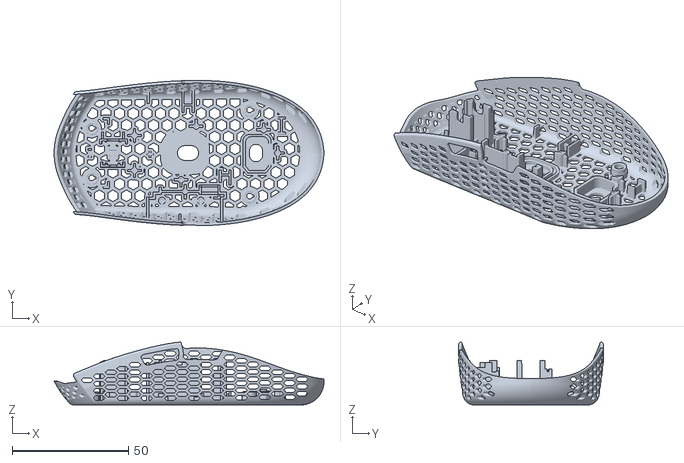
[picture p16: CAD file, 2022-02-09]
model/Logitech_G305-Ultralight-Honeycomb-Bottom-Shell-v2.stl
115.9 x 62.3 x 27.0

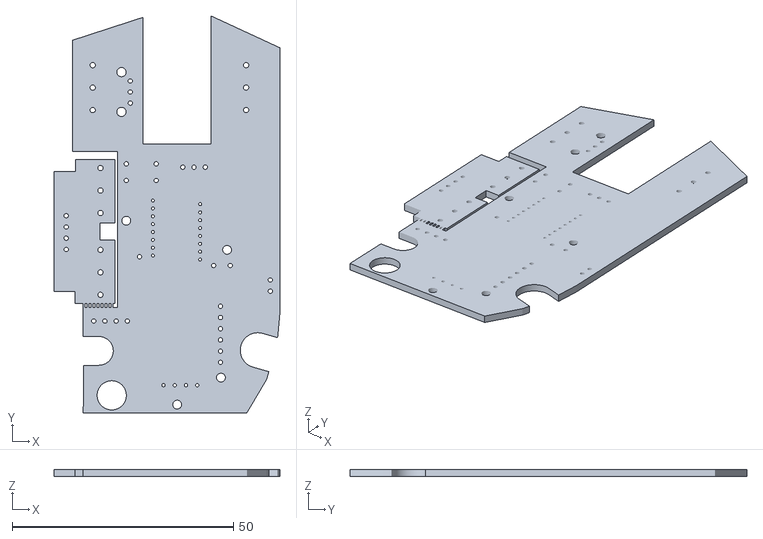
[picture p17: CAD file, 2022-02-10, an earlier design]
schematics_and_pcb/stl/rev1.stl
51.1 x 89.8 x 1.60

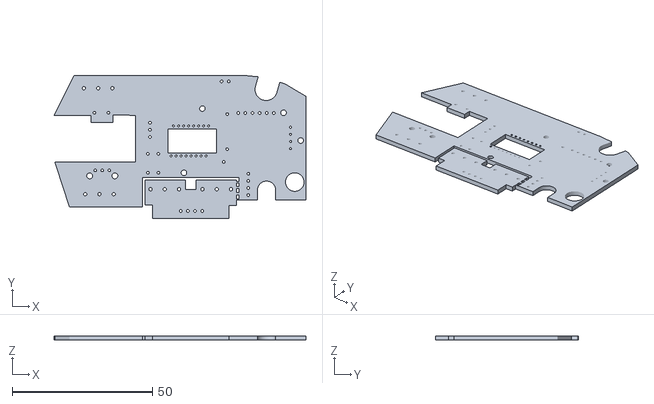
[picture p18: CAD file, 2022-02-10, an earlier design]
schematics_and_pcb/stl/rev2.stl
89.8 x 51.1 x 1.60

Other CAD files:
schematics_and_pcb/stl/rev5.stl
schematics_and_pcb/stl/rev3.stl
schematics_and_pcb/stl/rev4.stl

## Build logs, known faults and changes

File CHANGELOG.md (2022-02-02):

# Changelog

## 2022-01-20 Initial high level specification
- The initial high level specification was made.
## 2022-02-2 Specification
- A more detailed specification was made
- BOM was added with the components currently in the schematic

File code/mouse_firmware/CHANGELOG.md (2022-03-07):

# Changelog

## 2022-03-03

- src/pmw3389, (an experimental pmw3389 driver)
- rtic_pmw3389, (a simple example using the pmw3389 driver)

## 2022-03-02

- rtic_bare9_no_block, (an example of lock free access to multiple RTT channels). Uses `cargo-embed`.
- Embed.toml, (an example toml for `cargo-embed`)
- README.md, (updated with `cargo-embed` info)
  
## 2022-02-23

- stm32f4xx-hal bumped to 0.12.0 (only small fix to `rtic_bare6` needed)

- Examples
  - rtic_bare9, (example of a "good" reactive design)
  - rtic_usb_serial, (example of a VCP implementation)
  - rtic_usb_mouse, (example of a HID mouse implementation)

## 2022-02-22

- Examples
  - rtic_bare7, (using the stm32f4xx-hal)
  - rtic_bare7b, (using the embedded-hal and writing your own library)
  - rtic_bare8, (example of a "bad" (polling) design)

## 2022-02-18

- Examples
  - rtic_bare6, (clocking, measurements and function based peripheral API)
  - itm_rtic_blinky_48MHz, (showcase real-time ITM logging over SWO)

## 2022-02-17

- Examples
  - rtic_blinky, (showcase the stm32f4 API)
  - rtic_blinky_48mhz, (showcase the stm32fxx-hal for clocking)

## 2022-02-14

- Examples:
  - bare2..5, migrated to RTIC 1.0

## 2022-02-13

Migration and cleanup.

- Examples:
  - itm_rtic_hello, itm_rtic_hello2 (showcase ITM based single and dual port tracing)
  - rtic_crash, (Hard Fault handling)
  - rtic_hello, (showcase semihosting based tracing)
  - rtic_panic, (showcase panic handling)
  - rtt_rtic_hello, (showcase RTT based tracing)

- Exercises:
  - rtic_bare1, (arithmetics and panic handling)
  - rtic_bare2..5, in flux

## 2022-01-11

start migration to latest dependencies

- rtt_rtic_hello.rs, updated (rtt based tracing)
- rtic_hello.rs, updated (gdb based debug and semihosting)

## 2022-01-11, move to vesuvio, initial commit

## 2021-03-19

- `examples/itm_rtic_hello_48MHz.rs`, example to trace ITM, when processor runs at 48MHz, useful to debug USB applications.
  
- `.vscode/launch.json`, added 48MHz itm tracing profiles. (Now consistenly using `stlink.cfg`.)
  
## 2021-03-18

- `examples/usb-mouse.rs`, a very small example using external hid library.
  
## 2021-03-07

- `examples/rtic_bare7.rs`, using embedded HAL.
- `examples/rtic_bare8.rs`, serial communication, bad design.
- `examples/rtic_bare9.rs`, serial communication, good design.
  
## 2021-03-05

- `examples/rtic_bare6.rs`, setup and validate the clock tree.

## 2021-02-28

- `examples/rtic_bare2.rs`, raw timer access.
- `examples/rtic_bare3.rs`, timing abstractions.
- `examples/rtic_bare4.rs`, a simple bare metal peripheral access API.
- `examples/rtic_bare5.rs`, write your own C-like peripheral access API.

## 2021-02-26

- `examples/bare1.rs`, bare metal 101!
  
## 2021-02-23

- `examples/rtic_blinky.rs`, added instructions to terminal based debugging
  
## 2021-02-22

- `memory.x`, reduced flash size to 128k to match light-weight target
- `Cargo.toml`, updated dependencies to latest `stm32f4xx-hal/pac`

Some experiments (wip):

- `examples/rtt_rtic_i2c.rs`, spi emulation over i2c
- `src/pwm3389e`, driver using emulated spi

## 2021-02-16

- `rtt_rtic_usb_mouse` updated
  Notice, requires release build

## 2021-02-15

- Initial release for the e7020e course 2021

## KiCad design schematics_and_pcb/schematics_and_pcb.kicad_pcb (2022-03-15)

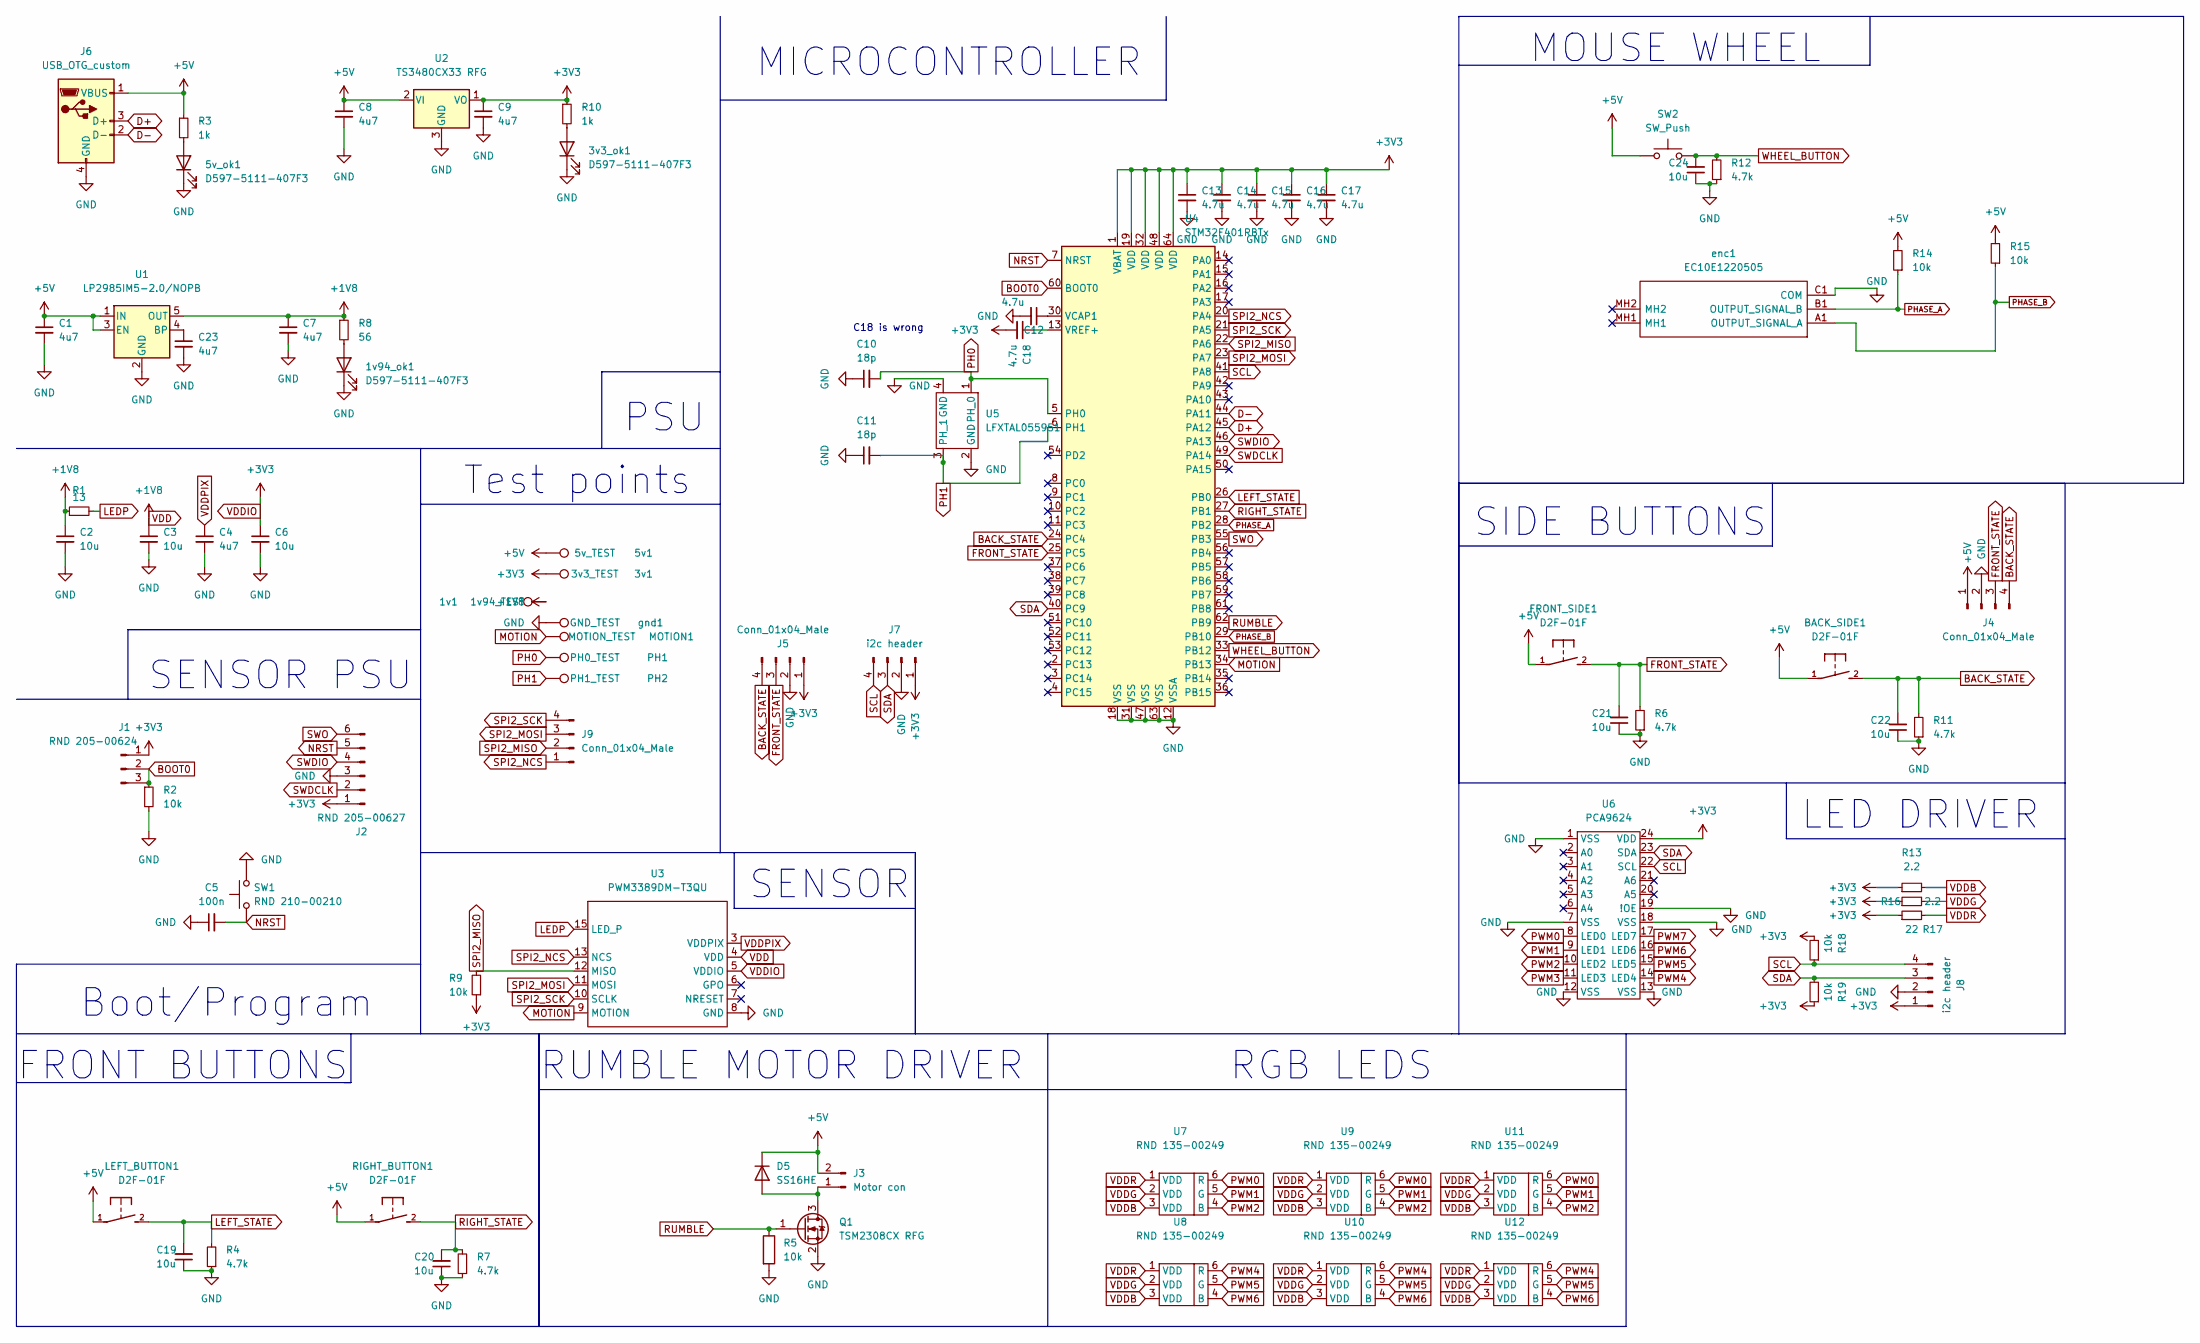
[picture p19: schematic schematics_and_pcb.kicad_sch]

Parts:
1v1: 1v94_TEST; PinHeader_1x01_P2.54mm_Vertical
1v94_ok1, 3v3_ok1, 5v_ok1: D597-5111-407F3; LED_0805_2012Metric_Pad1.15x1.40mm_HandSolder; part # D597-5111-407F3
3v1: 3v3_TEST; PinHeader_1x01_P2.54mm_Vertical
5v1: 5v_TEST; PinHeader_1x01_P2.54mm_Vertical
BACK_SIDE1: D2F-01F
C1, C4, C7, C8, C9, C23: 4u7; C_0805_2012Metric_Pad1.18x1.45mm_HandSolder
C2, C3, C6, C19, C20, C21, C22, C24: 10u; C_0805_2012Metric_Pad1.18x1.45mm_HandSolder
C5: 100n; C_0805_2012Metric_Pad1.18x1.45mm_HandSolder
C10, C11: 18p; C_0805_2012Metric_Pad1.18x1.45mm_HandSolder
C12, C13, C14, C15, C16, C17, C18: 4.7u; C_0805_2012Metric_Pad1.18x1.45mm_HandSolder
D5: SS16HE; SOD-323HE; part # SS16HE
FRONT_SIDE1: D2F-01F
J1: RND 205-00624; PinHeader_1x03_P2.54mm_Vertical
J2: RND 205-00627; PinHeader_1x06_P2.54mm_Vertical
J3: Motor con; PinSocket_1x02_P2.54mm_Vertical
J4, J5: Conn_01x04_Male; PinHeader_1x04_P2.54mm_Vertical
J6: USB_OTG_custom; USB_2.45
J7, J8: i2c header; PinHeader_1x04_P2.54mm_Vertical
J9: Conn_01x04_Male; PinHeader_1x04_P1.00mm_Vertical
LEFT_BUTTON1: D2F-01F; part # D2F-01F
MOTION1: MOTION_TEST; PinHeader_1x01_P2.54mm_Vertical
PH1: PH0_TEST; PinHeader_1x01_P2.54mm_Vertical
PH2: PH1_TEST; PinHeader_1x01_P2.54mm_Vertical
Q1: TSM2308CX RFG; SOT-23; part # TSM2308CX RFG
R1: 13; R_0805_2012Metric_Pad1.20x1.40mm_HandSolder; part # RND 155HP05W3F130JT5E
R2, R9, R14, R15, R18, R19: 10k; R_0805_2012Metric_Pad1.20x1.40mm_HandSolder; part # RT0805FRE0710KL
R3, R10: 1k; R_0805_2012Metric_Pad1.20x1.40mm_HandSolder; part # RC0805FR-071KL
R4, R6, R7, R11, R12: 4.7k; R_0805_2012Metric_Pad1.20x1.40mm_HandSolder; part # RC0805FR-074K7L
R5: 10k; R_0805_2012Metric_Pad1.20x1.40mm_HandSolder; part # RC0805FR-071KL
R8: 56; R_0805_2012Metric_Pad1.20x1.40mm_HandSolder; part # RND 155HP05W3F560JT5E
R13, R16: 2.2; R_0805_2012Metric_Pad1.20x1.40mm_HandSolder
R17: 22; R_0805_2012Metric_Pad1.20x1.40mm_HandSolder
RIGHT_BUTTON1: D2F-01F; part # D2F-01F
SW1: RND 210-00210; SW_Push_1P1T_NO_6x6mm_H9.5mm
SW2: SW_Push; evqP0E07; part # evqP0E07
U1: LP2985IM5-2.0/NOPB; SOT-23-5; part # LP2985IM5-2.0/NOPB
U2: TS3480CX33 RFG; SOT-23; part # TS3480CX33 RFG
U3: PWM3389DM-T3QU; PMW3389DM-T3QU; part # PWM3389DM-T3QU
U4: STM32F401RBTx; LQFP-64_10x10mm_P0.5mm
U5: LFXTAL055951
U6: PCA9624; TSSOP-24
U7, U8, U9, U10, U11, U12: RND 135-00249; RND_135-00249
enc1: EC10E1220505; Manufacturer_Part_Number EC10E1220505; Mouser Part Number 688-EC10E1220505
gnd1: GND_TEST; PinHeader_1x01_P2.54mm_Vertical

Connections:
+5V: 5v1.1, BACK_SIDE1.1, C1.1, C8.1, D5.1 (K), FRONT_SIDE1.1, J3.2, J4.1, J6.1 (VBUS), LEFT_BUTTON1.1, R3.1, R14.2, R15.2, RIGHT_BUTTON1.1, SW2.1, U1.1 (IN), U1.3 (EN), U2.2 (VI)
BACK_STATE: BACK_SIDE1.2, C22.2, J4.4, J5.4, R11.2, U4.24 (PC4)
BOOT0: J1.2, J1.3, R2.1, U4.60 (BOOT0)
D+: J6.3 (D+), U4.45 (PA12)
D-: J6.2 (D-), U4.44 (PA11)
FRONT_STATE: C21.2, FRONT_SIDE1.2, J4.3, J5.3, R6.2, U4.25 (PC5)
GND: 1v94_ok1.1 (K), 3v3_ok1.1 (K), 5v_ok1.1 (K), C1.2, C2.2, C3.2, C4.2, C5.1, C6.2, C7.2, C8.2, C9.2, C10.1, C11.1, C12.2, C13.2, C14.2, C15.2, C16.2, C17.2, C19.1, C20.1, C21.1, C22.1, C23.2, C24.1, J2.3, J4.2, J5.2, J6.4 (GND), J7.2, J8.2, Q1.2 (S), R2.2, R4.1, R5.2, R6.1, R7.1, R11.1, R12.1, SW1.2, U1.2 (GND), U2.3 (GND), U3.8 (GND), U4.12 (VSSA), U4.18 (VSS), U4.31 (VSS), U4.47 (VSS), U4.63 (VSS), U5.2 (GND), U5.4 (GND), U6.1 (VSS), U6.7 (VSS), U6.12 (VSS), U6.13 (VSS), U6.18 (VSS), U6.19 (!OE), enc1.C1 (COM), gnd1.1
LEDP: R1.2, U3.15 (LED_P)
LEFT_STATE: C19.2, LEFT_BUTTON1.2, R4.2, U4.26 (PB0)
MOTION: MOTION1.1, U3.9 (MOTION), U4.34 (PB13)
NRST: C5.2, J2.5, SW1.1, U4.7 (NRST)
unnamed: 1v94_ok1.2 (A), R8.2
unnamed: 3v3_ok1.2 (A), R10.2
unnamed: 5v_ok1.2 (A), R3.2
unnamed: C12.1, U4.30 (VCAP1)
unnamed: C18.1, U4.13 (VREF+)
unnamed: C23.1, U1.4 (BP)
unnamed: D5.2 (A), J3.1, Q1.3 (D)
PH0: C10.2, PH1.1, U4.5 (PH0), U5.1 (PH_0)
PH1: C11.2, PH2.1, U4.6 (PH1), U5.3 (PH_1)
PHASE_A: R14.1, U4.28 (PB2), enc1.B1 (OUTPUT_SIGNAL_B)
PHASE_B: R15.1, U4.29 (PB10), enc1.A1 (OUTPUT_SIGNAL_A)
PWM0: U6.8 (LED0), U7.6 (R), U9.6 (R), U11.6 (R)
PWM1: U6.9 (LED1), U7.5 (G), U9.5 (G), U11.5 (G)
PWM2: U6.10 (LED2), U7.4 (B), U9.4 (B), U11.4 (B)
PWM3: U6.11 (LED3)
PWM4: U6.14 (LED4), U8.6 (R), U10.6 (R), U12.6 (R)
PWM5: U6.15 (LED5), U8.5 (G), U10.5 (G), U12.5 (G)
PWM6: U6.16 (LED6), U8.4 (B), U10.4 (B), U12.4 (B)
PWM7: U6.17 (LED7)
RIGHT_STATE: C20.2, R7.2, RIGHT_BUTTON1.2, U4.27 (PB1)
RUMBLE: Q1.1 (G), R5.1, U4.62 (PB9)
SCL: J7.4, J8.4, R18.1, U4.41 (PA8), U6.22 (SCL)
SDA: J7.3, J8.3, R19.2, U4.40 (PC9), U6.23 (SDA)
SPI2_MISO: J9.2, R9.2, U3.12 (MISO), U4.22 (PA6)
SPI2_MOSI: J9.3, U3.11 (MOSI), U4.23 (PA7)
SPI2_NCS: J9.1, U3.13 (NCS), U4.20 (PA4)
SPI2_SCK: J9.4, U3.10 (SCLK), U4.21 (PA5)
SWDCLK: J2.2, U4.49 (PA14)
SWDIO: J2.4, U4.46 (PA13)
SWO: J2.6, U4.55 (PB3)
VDD: 1v1.1, C2.1, C3.1, C7.1, R1.1, R8.1, U1.5 (OUT), U3.4 (VDD)
VDDB: R13.2, U7.3 (VDD), U8.3 (VDD), U9.3 (VDD), U10.3 (VDD), U11.3 (VDD), U12.3 (VDD)
VDDG: R16.2, U7.2 (VDD), U8.2 (VDD), U9.2 (VDD), U10.2 (VDD), U11.2 (VDD), U12.2 (VDD)
VDDIO: 3v1.1, C6.1, C9.1, C13.1, C14.1, C15.1, C16.1, C17.1, C18.2, J1.1, J2.1, J5.1, J7.1, J8.1, R9.1, R10.1, R13.1, R16.1, R17.1, R18.2, R19.1, U2.1 (VO), U3.5 (VDDIO), U4.1 (VBAT), U4.19 (VDD), U4.32 (VDD), U4.48 (VDD), U4.64 (VDD), U6.24 (VDD)
VDDPIX: C4.1, U3.3 (VDDPIX)
VDDR: R17.2, U7.1 (VDD), U8.1 (VDD), U9.1 (VDD), U10.1 (VDD), U11.1 (VDD), U12.1 (VDD)
WHEEL_BUTTON: C24.2, R12.2, SW2.2, U4.33 (PB12)

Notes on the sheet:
LED DRIVER
Test points
PSU
SENSOR
C18 is wrong
FRONT BUTTONS
Boot/Program
SENSOR PSU
RGB LEDS
MICROCONTROLLER
RUMBLE MOTOR DRIVER
MOUSE WHEEL
SIDE BUTTONS

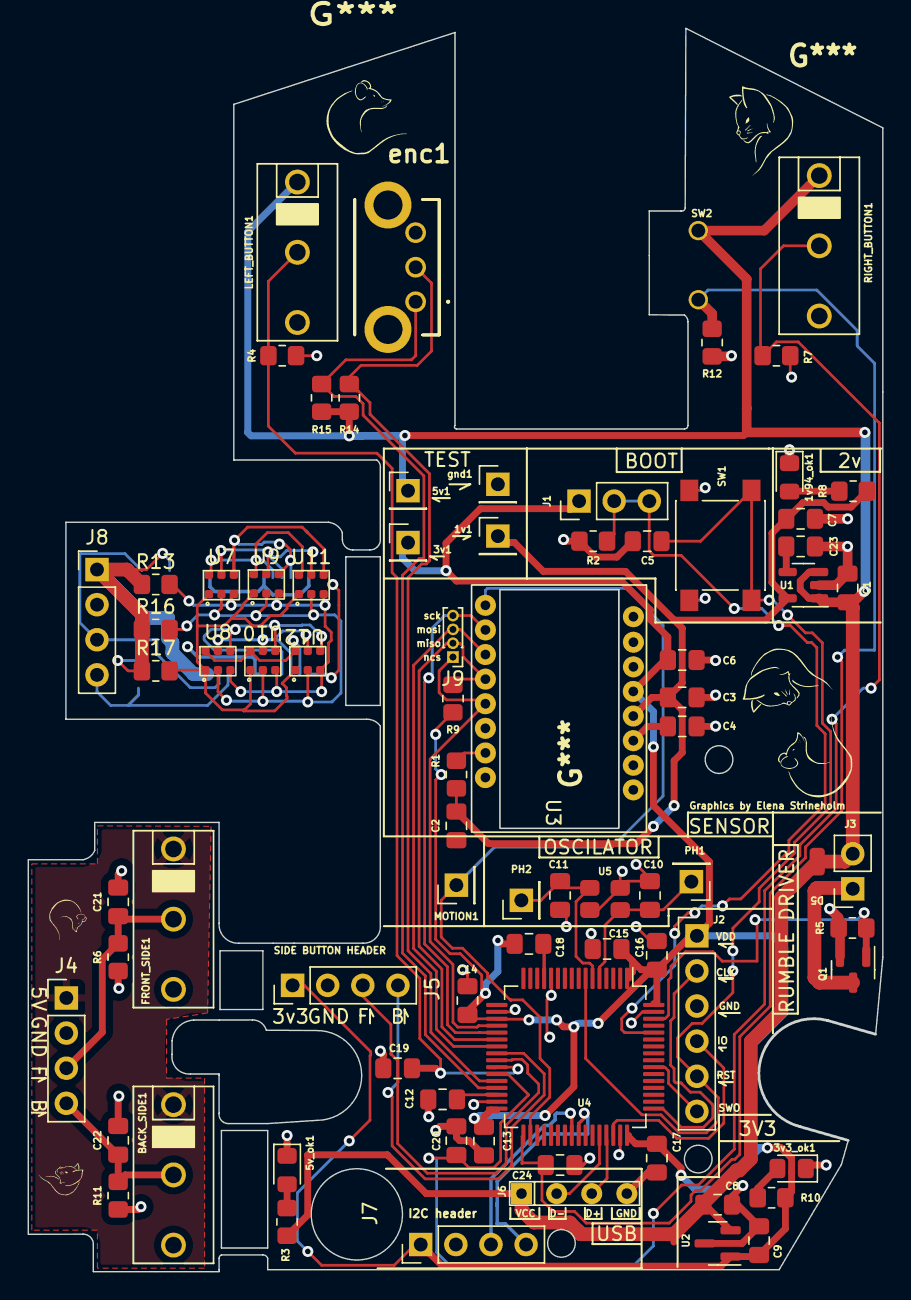
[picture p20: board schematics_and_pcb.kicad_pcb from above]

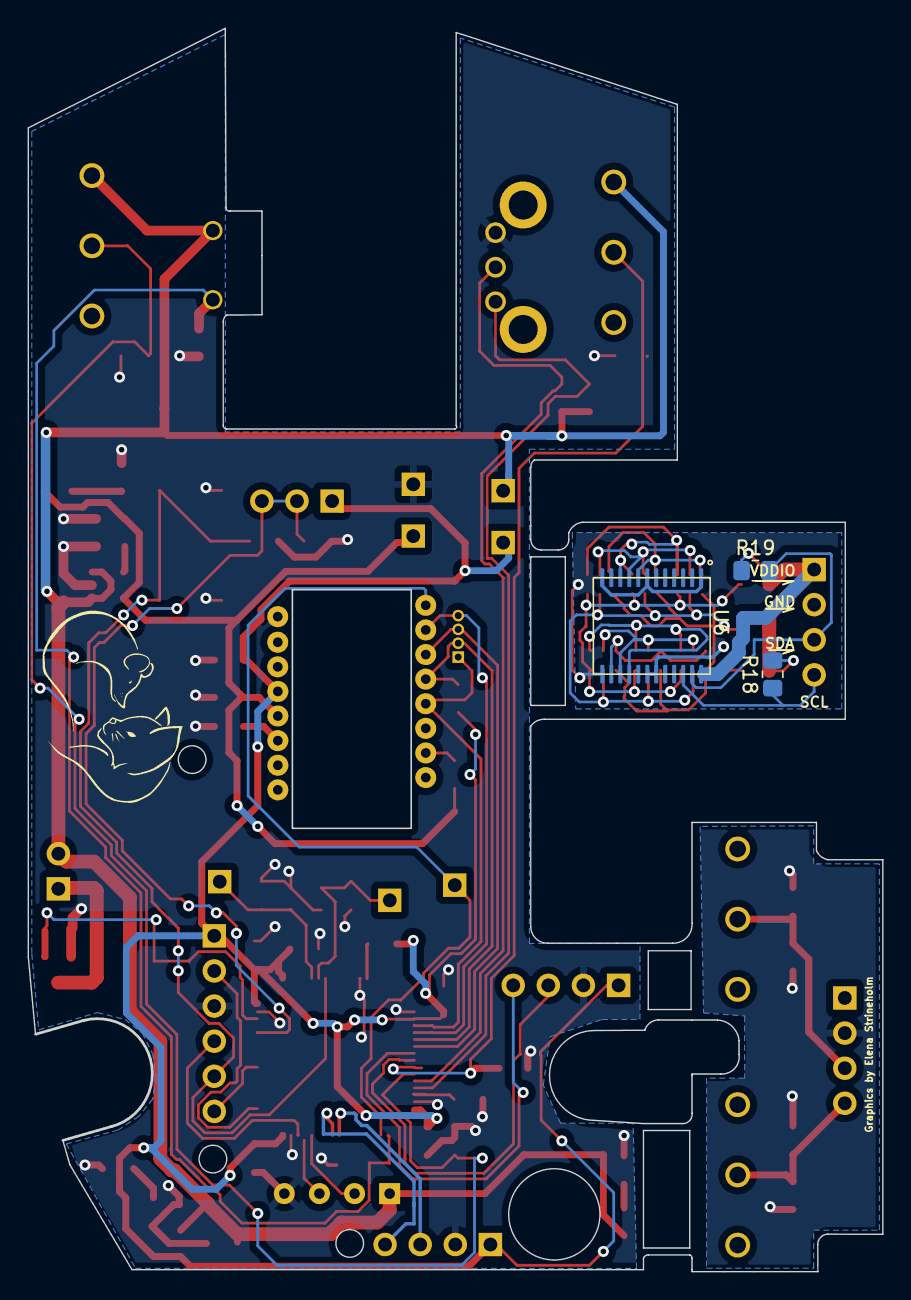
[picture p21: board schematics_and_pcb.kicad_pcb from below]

Board: 2 copper layers, 61.8 x 89.9 mm, 83 parts (3 on the bottom side), 46 nets.

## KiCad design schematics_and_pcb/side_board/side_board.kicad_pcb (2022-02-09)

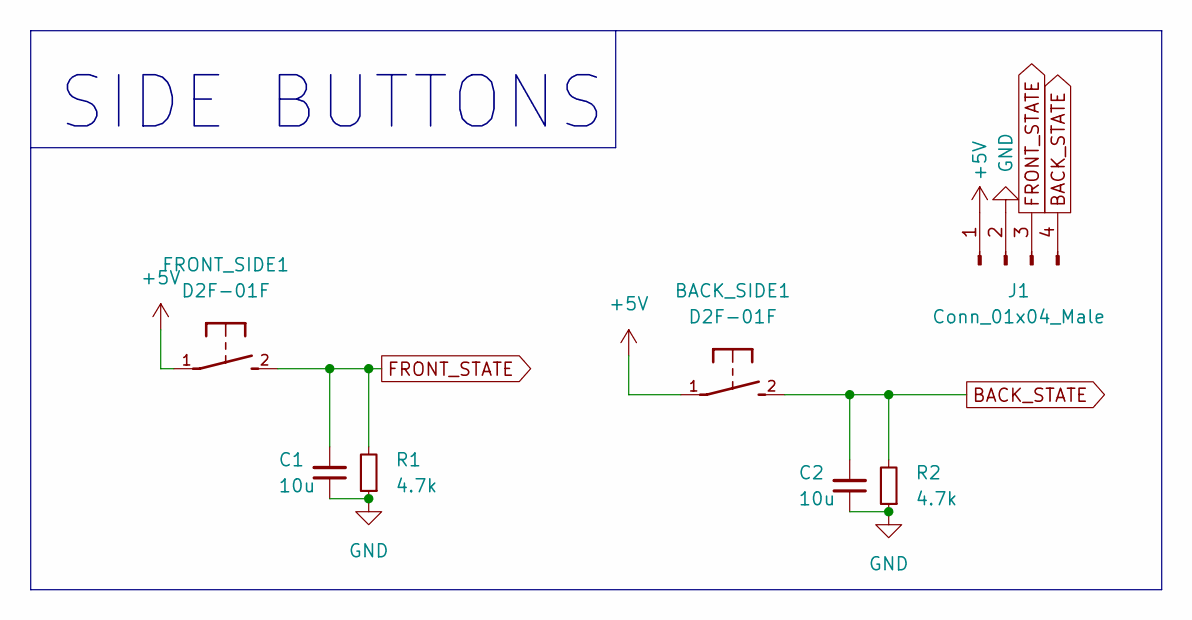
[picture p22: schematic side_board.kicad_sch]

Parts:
BACK_SIDE1: D2F-01F
C1, C2: 10u; C_0805_2012Metric_Pad1.18x1.45mm_HandSolder
FRONT_SIDE1: D2F-01F
J1: Conn_01x04_Male; PinHeader_1x04_P2.54mm_Vertical
R1, R2: 4.7k; R_0805_2012Metric_Pad1.20x1.40mm_HandSolder; part # RC0805FR-074K7L

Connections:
+5V: BACK_SIDE1.1, FRONT_SIDE1.1, J1.1
BACK_STATE: BACK_SIDE1.2, C2.2, J1.4, R2.2
FRONT_STATE: C1.2, FRONT_SIDE1.2, J1.3, R1.2
GND: C1.1, C2.1, J1.2, R1.1, R2.1

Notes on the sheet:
SIDE BUTTONS

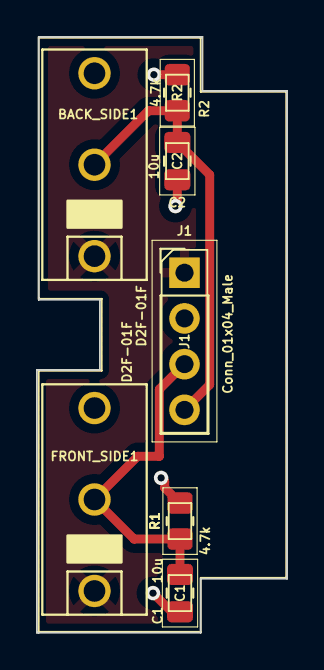
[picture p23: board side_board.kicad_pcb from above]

Board: 2 copper layers, 13.9 x 33.1 mm, 7 parts (0 on the bottom side), 4 nets.

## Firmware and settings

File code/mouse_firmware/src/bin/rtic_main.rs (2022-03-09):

//! rtic_usb_mouse.rs
//!
//! Mouse HID example
//!
//! What it covers:
//! - Mouse HID communication
//! - good design, interrupt driven polling
//!
//! In this case we use RTT, so change your runner accordingly in `.cargo/config`.
#![no_main]
#![no_std]

use panic_rtt_target as _;


#[rtic::app(device = stm32f4::stm32f411, dispatchers = [EXTI0])]
mod app {
    use rtt_target::{rprintln, rtt_init_print};
    use stm32f4xx_hal::otg_fs::{UsbBus, USB};
    use stm32f4xx_hal::prelude::*;
    use stm32f4xx_hal::gpio::*;
    use usb_device::{bus::UsbBusAllocator, prelude::*};
    use usbd_hid::{
        descriptor::{generator_prelude::*, MouseReport},
        hid_class::HIDClass,
    };

    use crate::hidDescriptors::MouseKeyboard;
    use crate::mouseKeyboardReport::MouseKeyboardState;
    use crate::bin::macroSystem::{MacroConfig, Function};
    
    type Button = ErasedPin<Input<PullUp>>;

    #[shared]
    struct Shared {
        mouse: MouseKeyboardState,
        macro_conf: MacroConfig
    }

    #[local]
    struct Local {
        usb_dev: UsbDevice<'static, UsbBus<USB>>,
        hid: HIDClass<'static, UsbBus<USB>>,
        button: Button
    }

    const POLL_INTERVAL_MS: u8 = 1;

    #[init(local = [EP_MEMORY: [u32; 1024] = [0; 1024], bus: Option<UsbBusAllocator<UsbBus<USB>>> = None])]
    fn init(cx: init::Context) -> (Shared, Local, init::Monotonics) {
        rtt_init_print!();
        rprintln!("init");
        let mut dp = cx.device;
        let cd = cx.core;

        let rcc = dp.RCC.constrain();

        let clocks = rcc.cfgr.sysclk(48.MHz()).require_pll48clk().freeze();

        let gpioa = dp.GPIOA.split();

        let usb = USB {
            usb_global: dp.OTG_FS_GLOBAL,
            usb_device: dp.OTG_FS_DEVICE,
            usb_pwrclk: dp.OTG_FS_PWRCLK,
            pin_dm: gpioa.pa11.into_alternate(),
            pin_dp: gpioa.pa12.into_alternate(),
            hclk: clocks.hclk(),
        };

        let gpioc = dp.GPIOC.split();
        let mut button = gpioc.pc13.into_pull_up_input().erase();
        let mut sys_cfg = dp.SYSCFG.constrain();

        // Enable interuppts for PC13
        button.make_interrupt_source(&mut sys_cfg);
        button.enable_interrupt(&mut dp.EXTI);
        button.trigger_on_edge(&mut dp.EXTI, Edge::RisingFalling);

        cx.local.bus.replace(UsbBus::new(usb, cx.local.EP_MEMORY));

        let hid = HIDClass::new(
            cx.local.bus.as_ref().unwrap(),
            MouseKeyboard::desc(),
            POLL_INTERVAL_MS,
        );

        let mouse = MouseKeyboardState::new();

        let mut macro_conf = MacroConfig::new();
        macro_conf.update_config(
            Function::PressKeyboard(0x4), Function::Nothing,
            Function::Nothing, Function::Nothing,
            Function::Nothing, Function::Nothing,
            Function::Nothing
        );

        let usb_dev =
            UsbDeviceBuilder::new(cx.local.bus.as_ref().unwrap(), UsbVidPid(0xc410, 0x0000))
                .manufacturer("e7020e")
                .product("Mouse")
                .serial_number("1337")
                .device_class(0) // Hid
                .build();

        (Shared {mouse, macro_conf}, Local { usb_dev, hid, button}, init::Monotonics())
    }

    // B1 is connected to PC13
    #[task(binds=EXTI15_10, local = [button], shared = [mouse, macro_conf])]
    fn button_pressed(mut cx: button_pressed::Context) {
        // this should be automatic
        cx.local.button.clear_interrupt_pending_bit();

        if cx.local.button.is_low() {
            rprintln!("button low");
            cx.shared.mouse.lock(|mouse| {
                cx.shared.macro_conf.lock(|macro_conf| {
                    macro_conf.push_left(mouse);
                });
            });
        } else {
            rprintln!("button high");
            cx.shared.mouse.lock(|mouse| {
                cx.shared.macro_conf.lock(|macro_conf| {
                    macro_conf.release_left(mouse);
                });
            });
        }
    }

    // interrupt generated each time the hid device is polled
    // in this example each 1ms (POLL_INTERVAL_MS = 1)
    #[task(
        binds=OTG_FS,
        local = [usb_dev, hid, first :bool = true, counter:u16 = 0],
        shared = [mouse]
    )]
    fn usb_fs(mut cx: usb_fs::Context) {
        let usb_fs::LocalResources {
            usb_dev,
            hid,
            first,
            counter,
        } = cx.local;

        if *first {
            rprintln!("first");
            *first = false;
        }

        // wraps around after 200ms
        *counter = (*counter + 1) % 200;
        let mov = match *counter {
            // reached after 100ms
            100 => {
                rprintln!("10");
                10
            }
            // reached after 200ms
            0 => {
                rprintln!("-10");
                -10
            }
            _ => 0,
        };

        cx.shared.mouse.lock(|mouse| {
            mouse.add_x_movement(mov);
        });

        cx.shared.mouse.lock(|mouse| {
            let report = mouse.get_report_and_reset();
            // push the report
            hid.push_input(&report).ok();
        });


        // update the usb device state
        if usb_dev.poll(&mut [hid]) {
            return;
        }
    }
}

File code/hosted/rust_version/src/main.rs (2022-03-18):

use hidapi::HidApi;

fn main() {
    println!("Printing all available hid devices:");

    match HidApi::new() {
        Ok(api) => {
            for device in api.device_list() {
                println!(
                    "VID {:04x}: PID {:04x}",
                    device.vendor_id(),
                    device.product_id()
                );
                println!("manufacturer {:?}", device.manufacturer_string());
                println!("product {:?}", device.product_string());
                println!("serial {:?}", device.serial_number());
            }

            // Open Iris

            match api.open(0xc410, 0x0000) {
                Ok(hd) => {
                    println!("open ok");

                    let mut buf = [0u8; 4];

                    loop {
                        hd.read(&mut buf).unwrap();
                        let u: u32 = u32::from_le_bytes(buf);
                        println!("buf {:?}, {}", buf, u);
                    }
                }
                Err(err) => println!("error {:?}", err),
            }
        }
        Err(e) => {
            eprintln!("Error: {}", e);
        }
    }
}

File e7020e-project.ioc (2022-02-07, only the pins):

Mcu.UserName=STM32F401RBTx
PA11.Signal=USB_OTG_FS_DM
PA12.Signal=USB_OTG_FS_DP
PA4.Signal=SPI1_NSS
PA5.Signal=SPI1_SCK
PA6.Signal=SPI1_MISO
PA7.Signal=SPI1_MOSI

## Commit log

2022-02-01 added a start point for the design
    [schematics_and_pcb.kicad_pcb, schematics_and_pcb.kicad_sch]
2022-02-01 prettier lables
    [schematics_and_pcb.kicad_sch]
2022-02-01 added left and right buttons
    [schematics_and_pcb.kicad_pcb, schematics_and_pcb.kicad_sch]
2022-02-01 added more buttons and scroll wheel
    [schematics_and_pcb.kicad_sch]
2022-02-01 added BOM
    [schematics_and_pcb.csv, schematics_and_pcb.kicad_sch]
2022-02-02 Added a possible motor drive to schematic.
    [schematics_and_pcb.kicad_sch]
2022-02-02 added a buttons etc
    [BOM.csv, schematics_and_pcb.csv]
2022-02-03 added motor driver
    [schematics_and_pcb.kicad_sch]
2022-02-04 done with main board outline
    [schematics_and_pcb.kicad_pcb, schematics_and_pcb.kicad_sch]
2022-02-04 main board outline tuned
    [schematics_and_pcb.kicad_pcb]
2022-02-04 some highspeed signal traces
    [schematics_and_pcb.kicad_pcb]
2022-02-04 layout of main board almost done
    [schematics_and_pcb.kicad_pcb]
2022-02-07 new layout
    [Unnamed-schematics_and_pcb 1.stl, Unnamed1-schematics_and_pcb 1.stl, rev3.stl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]
2022-02-07 added mounting holes
    [rev4.stl, rev5.stl, schematics_and_pcb.kicad_pcb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]
2022-02-07 added routes for all signals except buttons and scrollwheel
    [rev6.stl, schematics_and_pcb.kicad_pcb, schematics_and_pcb.kicad_sch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]
2022-02-07 added routes for all buttons
    [schematics_and_pcb.kicad_pcb, schematics_and_pcb.kicad_sch]
2022-02-07 added a logo
    [schematics_and_pcb.kicad_pcb]
2022-02-08 added pin for the rumble
    [schematics_and_pcb.kicad_pcb, schematics_and_pcb.kicad_sch]
2022-02-08 moved lib
    [schematics_and_pcb.kicad_pcb]
2022-02-08 some fixes
    [Unnamed-schematics_and_pcb 1.stl, Unnamed1-schematics_and_pcb 1.stl, rev3.stl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]
2022-02-08 changed to custom usb connector with only 4 pins.
    [schematics_and_pcb.kicad_pcb, schematics_and_pcb.kicad_sch]
2022-02-08 fixed some drc issues
    [schematics_and_pcb.kicad_pcb]
2022-02-09 filled out the readme
    [BOM.csv, Logitech_G305-Ultralight-Honeycomb-Bottom-Shell-v2.stl, g305_subframe.stl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]
2022-02-09 fixed some of the routing
    [BOM.csv, side_board.kicad_pcb]
2022-02-09 added schematic to the readme
    [schematics_and_pcb.kicad_sch]
2022-02-09 adjusted motor driver resistor
    [schematics_and_pcb.kicad_sch]
2022-02-10 probs final version
    [BOM.csv, rev1.stl, rev2.stl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]
2022-02-11 added RGB LEDS
    [schematics_and_pcb.kicad_pcb, schematics_and_pcb.kicad_sch]
2022-02-11 some patches
    [schematics_and_pcb.kicad_pcb]
2022-02-11 added pullups
    [schematics_and_pcb.kicad_pcb, schematics_and_pcb.kicad_sch]
2022-02-11 done with the bom
    [schematics_and_pcb.csv, schematics_and_pcb.kicad_pcb, schematics_and_pcb.kicad_sch]
2022-02-11 updated the bom
    [BOM.csv, BOM.xlsx, rev3.stl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]
2022-03-15 fixed board
    [Ivar_Erik_rev1.kicad_pcb, Ivar_Erik_rev1.step, rev5.stl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]
2022-03-18 fixed to use right hid descriptor
    [rtic_macro_test2.rs]
2022-03-18 moved sensor to mouse report object
2022-03-18 button test
2022-03-20 rgb driver almost done
2022-03-22 modified usb driver, hopefully nothing broke
    [rtic_simple_mouse.rs]
2022-03-25 driver rework
2022-03-25 host almost done
    [mouse-config.cfg]
2022-03-25 host side kinda done
    [hello_world.cfg, mouse-config.cfg]
2022-03-25 host end improved
    [hello_world.cfg, usefull.cfg]
2022-03-26 last minute
    [example.cfg, ivar.cfg]
2022-03-26 updated config
    [ivar.cfg]
